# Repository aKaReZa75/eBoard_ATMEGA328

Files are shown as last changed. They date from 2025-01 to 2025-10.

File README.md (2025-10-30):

# ATMEGA328 Board
This repository involves designing, assembling, and testing an educational header board for the ATMEGA328 AVR microcontroller, compatible with the Arduino UNO.

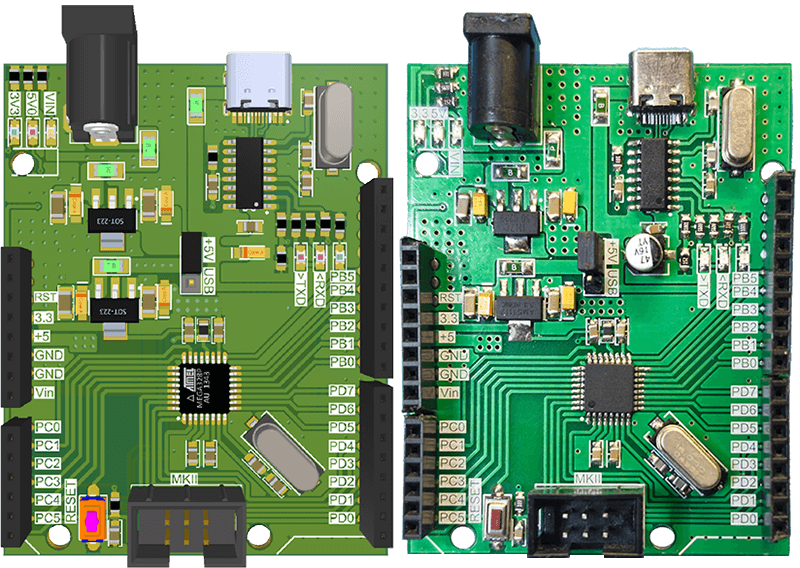
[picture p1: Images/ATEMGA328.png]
ATMEGA328 Shield


> [!IMPORTANT]
> Before sending the board files for PCB fabrication, **always make sure you are using the latest released version** of the project.
> Hardware issues or design flaws might exist in earlier versions and could be fixed in newer releases.
> To avoid costly mistakes and ensure the best performance, always refer to the **[Releases](../../releases)** section, where all known issues, updates, and version-specific notes are clearly documented.

## ATmega328 Pin Mapping Table
| **Arduino Pin** | **ATmega328 Pin** | **Functionality** |
| :---: | :---: | :--- |
| Analog Pin A0 | PC0 (PORTC, PIN0) | ADC0 |
| Analog Pin A1 | PC1 (PORTC, PIN1) | ADC1 |
| Analog Pin A2 | PC2 (PORTC, PIN2) | ADC2 |
| Analog Pin A3 | PC3 (PORTC, PIN3) | ADC3 |
| Analog Pin A4 | PC4 (PORTC, PIN4) | I2C (SDA) / ADC4 |
| Analog Pin A5 | PC5 (PORTC, PIN5) | I2C (SCL) / ADC5 |
| Digital Pin D0  | PD0 (PORTD, PIN0) | USART (RXD) |
| Digital Pin D1  | PD1 (PORTD, PIN1) | USART (TXD) |
| Digital Pin D2  | PD2 (PORTD, PIN2) | External Interrupt (INT0) |
| Digital Pin D3  | PD3 (PORTD, PIN3) | External Interrupt (INT1) / PWM (OC2B) |
| Digital Pin D4  | PD4 (PORTD, PIN4) | Timer/Counter (XCK/T0) |
| Digital Pin D5  | PD5 (PORTD, PIN5) | PWM (OC0B) / Timer1 |
| Digital Pin D6  | PD6 (PORTD, PIN6) | PWM (OC0A) / Analog Comparator |
| Digital Pin D7  | PD7 (PORTD, PIN7) | Analog Comparator Input |
| Digital Pin D8  | PB0 (PORTB, PIN0) | ICP1 / Clock Output (CLKO) |
| Digital Pin D9  | PB1 (PORTB, PIN1) | PWM (OC1A) |
| Digital Pin D10 | PB2 (PORTB, PIN2) | PWM (OC1B) / SPI (SS) |
| Digital Pin D11 | PB3 (PORTB, PIN3) | PWM (OC2A) / SPI (MOSI) |
| Digital Pin D12 | PB4 (PORTB, PIN4) | SPI (MISO) |
| Digital Pin D13 | PB5 (PORTB, PIN5) | SPI (SCK) / LED\_BUILTIN |

---

### **ADC (Analog-to-Digital Converter)**
| **Arduino Pin** | **ATmega328 Pin** | **ADC Channel** | **Other Functionality** |
| --- | --- | --- | --- |
| A0 | PC0 | ADC0 | — |
| A1 | PC1 | ADC1 | — |
| A2 | PC2 | ADC2 | — |
| A3 | PC3 | ADC3 | — |
| A4 | PC4 | ADC4 | I2C SDA |
| A5 | PC5 | ADC5 | I2C SCL |

### **Analog Comparator**
| **Arduino Pin** | **ATmega328 Pin** | **Functionality** |
| --- | --- | --- |
| D6 | PD6 | AIN0 |
| D7 | PD7 | AIN1 |

### **External Interrupts**
| **Arduino Pin** | **ATmega328 Pin** | **Interrupt** |
| --- | --- | --- |
| D2 | PD2 | INT0 |
| D3 | PD3 | INT1 |

### **Timers / PWM Outputs**
| **Arduino Pin** | **ATmega328 Pin** | **PWM / Timer** |
| --- | --- | ---|
| D6 | PD6 | OC0A (PWM) |
| D5 | PD5 | OC0B (PWM) |
| D9 | PB1 | OC1A (PWM) |
| D10 | PB2 | OC1B (PWM) |
| D11 | PB3 | OC2A (PWM) |
| D3 | PD3 | OC2B (PWM) |

| **Arduino Pin** | **ATmega328 Pin** | **Special Timer Function** |
| --- | --- | --- |
| D4 | PD4 | **T0** — Timer/Counter0 External Clock |
| D5 | PD5 | **T1** — Timer/Counter1 External Clock |
| D8 | PB0 | **ICP1** — Input Capture for Timer1 / CLKO |
| D6 | PD6 | AIN0 — Used in Analog Comparator (shared)  |
| D7 | PD7 | AIN1 — Used in Analog Comparator (shared)  |

### **USART (Serial Communication)**
| **Arduino Pin** | **ATmega328 Pin** | **USART Function** |
| --- | --- | --- |
| D0 | PD0 | RXD (Receive) |
| D1 | PD1 | TXD (Transmit) |

### **I2C Interface**
| **Arduino Pin** | **ATmega328 Pin** | **I2C Signal** |
| --- | --- | --- |
| A4 | PC4 | SDA |
| A5 | PC5 | SCL |

### **SPI Interface**
| **Arduino Pin** | **ATmega328 Pin** | **SPI Signal** |
| --- | --- | --- |
| D10 | PB2 | SS |
| D11 | PB3 | MOSI |
| D12 | PB4 | MISO |
| D13 | PB5 | SCK |

### **Other / General Purpose**
| **Arduino Pin** | **ATmega328 Pin** | **Functionality** |
| --- | --- | --- |
| D13 | PB5 | `LED_BUILTIN` / SPI Clock (SCK) |
| D12 | PB4 | **CKOUT** (System Clock Output) /SPI MISO  |

---

<table>
  <tr>
  <td valign="top">
  
  > [!TIP]  
  > If you're looking to better understand how to navigate and use my GitHub repositories — including exploring their structure, downloading or cloning projects, submitting issues, and asking questions,  
  > everything you need is clearly explained in this video:  
  > [aKaReZa 95 - Programming, Git - PART B](https://youtu.be/zYiUItVFRqQ)  
  > Make sure to check it out!
  
  </td>
    <td width="360" valign="middle" style="padding: 0;">
      <a href="https://youtu.be/zYiUItVFRqQ">
       aKaReZa 95 - Programming, Git - PART B Thumbnail
      </a>
    </td>
  </td>
  </tr>

<tr>
  <td valign="top">
  
  > [!IMPORTANT]
  > Begin your embedded systems journey with clarity and purpose. This episode outlines a structured roadmap for mastering microcontrollers, communication protocols, hardware design, and project development.  
  > Learn how to choose your specialization, follow curated playlists, and engage effectively with the community—ideal for learners seeking a scalable, goal-driven path into embedded engineering.  
  > [aKaReZa 124 – Embedded Systems Roadmap](https://youtu.be/3QYfv7A7aMc)  
  > Watch it now to kickstart your journey!
  
  </td>
  <td width="360" valign="middle" style="padding: 0;">
    <a href="https://youtu.be/3QYfv7A7aMc">
      aKaReZa 124 – Embedded Systems Roadmap Thumbnail
    </a>
  </td>
</tr>

  <tr>
  <td colspan="3">

  > [!CAUTION]
  > It is absolutely critical that you carefully read every single word of this document, line by line, to ensure you don't miss any details. Nothing can be overlooked.
      
  </td>
  </tr>  
</table>

## Detailed Description
| Aspect | Description |
|---|---|
| PCB Design Software  | Altium  V24.2.2 |
| PCB Layers | 2-Layer FR4 |
| Microcontroller | ATMEGA328 |
| Pin Type | Arduino UNO |
| Converter IC | CH340 |
| USB Port | TYPE-C |

## Resources

> [!TIP]
> The resources are detailed in the sections below.  
> To access any of them, simply click on the corresponding blue link.

- [Altium Library](https://github.com/aKaReZa75/Altium-Library)  
  ---  
   All PCB designs across all repositories and projects are built using this Altium Designer component library. It contains a wide range of verified footprints, schematic symbols, and 3D models, ensuring consistency and accuracy in PCB designs. If you're working on a new PCB, using this library will save you time and minimize errors.

- [PCB & Electronics Design Training](https://github.com/aKaReZa75/PCB)  
  ---  
  This repository is dedicated to **learning PCB design and electronics from scratch**. It covers everything from circuit theory to practical PCB layout techniques, including routing strategies, best practices, and component placement. Whether you're a beginner or an experienced designer, this resource will help you **improve your PCB design skills and create professional-quality boards**.

- [AVR Microcontroller Training](https://github.com/aKaReZa75/AVR)  
  ---  
  This repository provides a **comprehensive guide to AVR microcontroller programming**, covering everything from the fundamentals to advanced firmware development. Learn about **AVR architecture, peripheral interfacing, timers, interrupts, communication protocols**, and more through hands-on projects and real-world examples. Whether you're just starting or looking to refine your embedded programming skills, this resource will help you master AVR development.

- [Shopping Link](./ShoppingLink.md)  
  ---
  This document provides links to trusted suppliers where you can purchase all the essential components for this project, ensuring quality and reliability.

## Project Videos

```plaintext
Educational Boards
   ├── [aKaReZa 74 - eBoard, ATMEGA328 - PART A]
   │   ├─ Schematic — Voltage reg, UNO pinout, crystal, ADC filter.
   │   ├─ Communication — USBtoTTL + UART indicator.
   │   └─ Features — Auto Prog and library usage.
   │
   ├── [aKaReZa 76 - eBoard, ATMEGA328 - PART B]
   │   ├─ Fixes — Schematic issues and fuse improvements.
   │   ├─ Enhancements — USB Type-C, UART LEDs, voltage divider.
   │   └─ PCB Prep — Placement and routing readiness.
   │
   ├── [aKaReZa 88 - eBoard, ATMEGA328 - PART C]
   │   ├─ Routing — GPIO, USB, MCU, power tracks.
   │   ├─ Optimization — Polygon tool and hierarchical layout.
   │   └─ GitHub — Pull Request and version control.
   │
   └── [aKaReZa 102 - Repair, ATMEGA328 Soldering]
       ├─ Assembly — Voltage tests, MCU soldering, USB Type-C.
       ├─ Conversion — CH340 setup and verification.
       └─ Testing — Section-by-section validation.
```

<table style="border-collapse: collapse;">
  <tr>
    <td valign="top" style="padding: 0 10px;">
      <h3 style="margin: 0;">
        <a href="https://youtu.be/-ttv7IQRaWA">aKaReZa 74 – eBoard, ATMEGA328 - PART A</a>
      </h3>
      <p style="margin: 8px 0 0;">
        This video is the first in a new series called eBoard, which stands for Educational Boards. In this video, we design the schematic for an educational header board specifically for the ATMEGA328 microcontroller used in the channel's tutorials.
      </p>
    </td>
    <td width="360" valign="top" style="padding: 0;">
      <a href="https://youtu.be/-ttv7IQRaWA">
        aKaReZa 74 – eBoard, ATMEGA328 - PART A Thumbnail
      </a>
    </td>
  </tr>

  <tr>
    <td valign="top" style="padding: 0 10px;">
      <h3 style="margin: 0;">
        <a href="https://youtu.be/Ipy6SqzdZnI">aKaReZa 76 – eBoard, ATMEGA328 - PART B</a>
      </h3>
      <p style="margin: 8px 0 0;">
        In this video, we fix a few issues in the schematic, upgrade and change several sections, and then transfer all components to the PCB. We arrange the components and prepare them for routing.
      </p>
    </td>
    <td width="360" valign="top" style="padding: 0;">
      <a href="https://youtu.be/Ipy6SqzdZnI">
        aKaReZa 76 – eBoard, ATMEGA328 - PART B Thumbnail
      </a>
    </td>
  </tr>

  <tr>
    <td valign="top" style="padding: 0 10px;">
      <h3 style="margin: 0;">
        <a href="https://youtu.be/WwyNDgpCwrc">aKaReZa 88 – eBoard, ATMEGA328 - PART C</a>
      </h3>
      <p style="margin: 8px 0 0;">
        In this video, we complete the routing for the ATMEGA328 educational board and get familiar with related tips.
      </p>
    </td>
    <td width="360" valign="top" style="padding: 0;">
      <a href="https://youtu.be/WwyNDgpCwrc">
        aKaReZa 88 – eBoard, ATMEGA328 - PART C Thumbnail
      </a>
    </td>
  </tr>

  <tr>
    <td valign="top" style="padding: 0 10px;">
      <h3 style="margin: 0;">
        <a href="https://youtu.be/j-jOPXrMTt0">aKaReZa 102 – Repair, ATMEGA328 Soldering</a>
      </h3>
      <p style="margin: 8px 0 0;">
        Step-by-step soldering of an ATMEGA328-based board, covering power input, voltage regulators (12V, 5V, 3.3V), microcontroller placement, USB Type-C port installation, CH340 for USB-to-UART conversion, final connections, bootloader programming, and full board testing to ensure proper functionality.
      </p>
    </td>
    <td width="360" valign="top">
      <a href="https://youtu.be/j-jOPXrMTt0">
        aKaReZa 102 – Repair, ATMEGA328 Soldering Thumbnail
      </a>
    </td>
  </tr>

</table>

# 💻 How to Use Git and GitHub
To access the repository files and save them on your computer, there are two methods available:
1. **Using Git Bash and Cloning the Repository**
   - This method is more suitable for advanced users and those familiar with command-line tools.
   - By using this method, you can easily receive updates for the repository.

2. **Downloading the Repository as a ZIP file**
   - This method is simpler and suitable for users who are not comfortable with command-line tools.
   - Note that with this method, you will not automatically receive updates for the repository and will need to manually download any new updates.
     
## Clone using the URL.
First, open **Git Bash** :
-  Open the folder in **File Explorer** where you want the library to be stored.
-  **Right-click** inside the folder and select the option **"Open Git Bash here"** to open **Git Bash** in that directory.

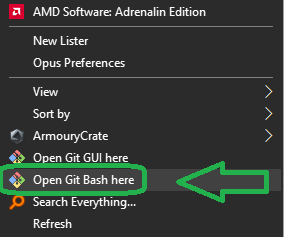
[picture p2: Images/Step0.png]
open Git Bash


> [!NOTE] 
> If you do not see the "Open Git Bash here" option, it means that Git is not installed on your system.  
> You can download and install Git from [this link](https://git-scm.com/downloads).  
> For a tutorial on how to install and use Git, check out [this video](https://youtu.be/BsykgHpmUt8).
  
-  Once **Git Bash** is open, run the following command to clone the repository:

 ```bash
git clone https://github.com/aKaReZa75/eBoard_ATMEGA328.git
```
- You can copy the above command by either:
- Clicking on the **Copy** button on the right of the command.
- Or select the command text manually and press **Ctrl + C** to copy.
- To paste the command into your **Git Bash** terminal, use **Shift + Insert**.

Clone the Repository

- Then, press Enter to start the cloning operation and wait for the success message to appear.

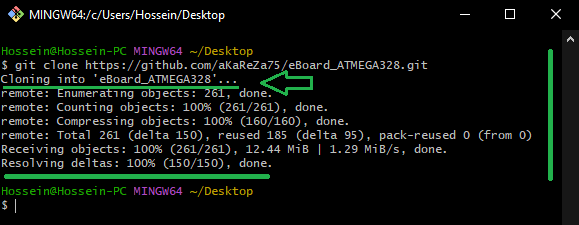
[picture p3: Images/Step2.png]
Open the Library File


> [!IMPORTANT]
> Please keep in mind that the numbers displayed in the image might vary when you perform the same actions.  
> This is because repositories are continuously being updated and expanded. Nevertheless, the overall process remains unchanged.

> [!NOTE]
> Advantage of Cloning the Repository:  
> - **Receiving Updates:** By cloning the repository, you can easily and automatically receive new updates.  
> - **Version Control:** Using Git allows you to track changes and revert to previous versions.  
> - **Team Collaboration:** If you are working on a project with a team, you can easily sync changes from team members and collaborate more efficiently.  

## Download Zip
If you prefer not to use Git Bash or the command line, you can download the repository directly from GitHub as a ZIP file.  
Follow these steps:  
1. Navigate to the GitHub repository page and Locate the Code button:
- On the main page of the repository, you will see a green Code button near the top right corner.

2. Download the repository:
- Click the Code button to open a dropdown menu.
- Select Download ZIP from the menu.

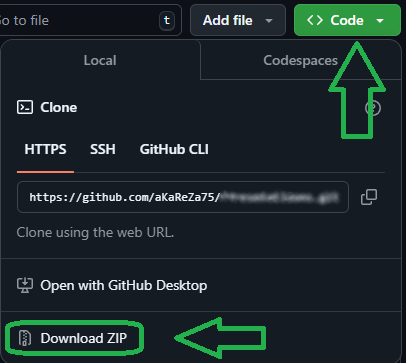
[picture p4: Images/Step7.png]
Download Zip
    

3. Save the ZIP file:
- Choose a location on your computer to save the ZIP file and click Save.

4. Extract the ZIP file:
- Navigate to the folder where you saved the ZIP file.
- Right-click on the ZIP file and select Extract All... (Windows) or use your preferred extraction tool.
- Choose a destination folder and extract the contents.

5. Access the repository:
- Once extracted, you can access the repository files in the destination folder.

> [!IMPORTANT]
> - No Updates: Keep in mind that downloading the repository as a ZIP file does not allow you to receive updates.    
>   If the repository is updated, you will need to download it again manually.  
> - Ease of Use: This method is simpler and suitable for users who are not comfortable with Git or command-line tools.

# 📝 How to Ask Questions
If you have any questions or issues, you can raise them through the **"Issues"** section of this repository. Here's how you can do it:  

1. Navigate to the **"Issues"** tab at the top of the repository page.  

  Issues

2. Click on the **"New Issue"** button.  
   
  New Issue

3. In the **Title** field, write a short summary of your issue or question.  

4. In the "Description" field, detail your question or issue as thoroughly as possible. You can use text formatting, attach files, and assign the issue to someone if needed. You can also use text formatting (like bullet points or code snippets) for better readability.  

5. Optionally, you can add **labels**, **type**, **projects**, or **milestones** to your issue for better categorization.  

6. Click on the **"Submit new issue"** button to post your question or issue.
   
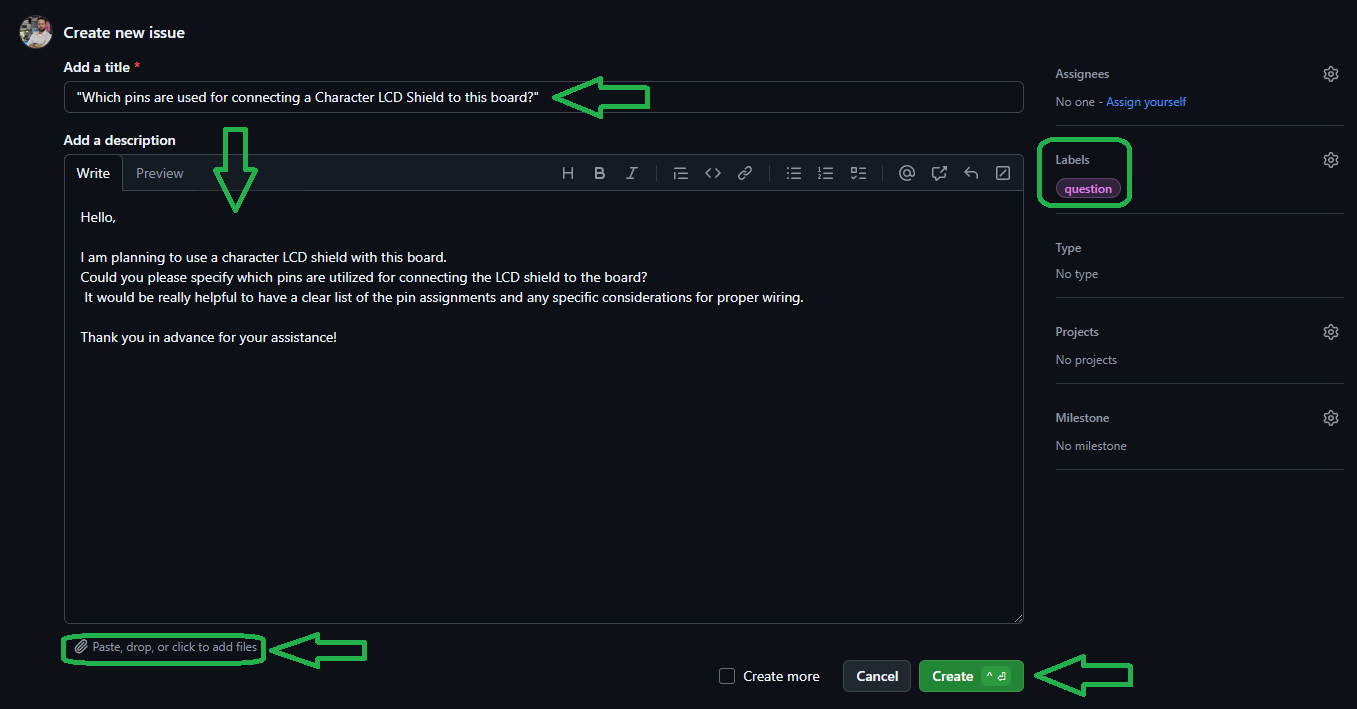
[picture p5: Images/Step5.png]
Submeet New Issue
  

I will review and respond to your issue as soon as possible. Your participation helps improve the repository for everyone!  

> [!TIP]
> - Before creating a new issue, please check the **"Closed"** section to see if your question has already been answered.  
>   Closed section  
> - Write your question clearly and respectfully to ensure a faster and better response.  
> - While the examples provided above are in English, feel free to ask your questions in **Persian (فارسی)** as well.  
> - There is no difference in how they will be handled!  

> [!NOTE]
> Pages and interfaces may change over time, but the steps to create an issue generally remain the same.

# 🤝 Contributing to the Repository
To contribute to this repository, please follow these steps:
1. **Fork the Repository**  
2. **Clone the Forked Repository**  
3. **Create a New Branch**  
4. **Make Your Changes**  
5. **Commit Your Changes**  
6. **Push Your Changes to Your Forked Repository**  
7. **Submit a Pull Request (PR)**  

> [!NOTE]
> Please ensure your pull request includes a clear description of the changes you’ve made.
> Once submitted, I will review your contribution and provide feedback if necessary.

# 🌟 Support Me
If you found this repository useful:
- Subscribe to my [YouTube Channel](https://www.youtube.com/@aKaReZa75).
- Share this repository with others.
- Give this repository and my other repositories a star.
- Follow my [GitHub account](https://github.com/aKaReZa75).

# 📜 License
This project is licensed under the GPL-3.0 License. This license grants you the freedom to use, modify, and distribute the project as long as you:
- Credit the original authors: Give proper attribution to the original creators.
- Disclose source code: If you distribute a modified version, you must make the source code available under the same GPL license.
- Maintain the same license: When you distribute derivative works, they must be licensed under the GPL-3.0 too.
- Feel free to use it in your projects, but make sure to comply with the terms of this license.
  
# ✉️ Contact Me
Feel free to reach out to me through any of the following platforms:
- 📧 [Email: aKaReZa75@gmail.com](mailto:aKaReZa75@gmail.com)
- 🎥 [YouTube: @aKaReZa75](https://www.youtube.com/@aKaReZa75)
- 💼 [LinkedIn: @akareza75](https://www.linkedin.com/in/akareza75)

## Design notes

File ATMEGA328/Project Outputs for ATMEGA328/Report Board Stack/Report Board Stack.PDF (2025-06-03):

# Board Stack Report

Stack Up | Layer Stack
Layer | Board Layer Stack | Name | Material | Thickness Constant Dk | | | Coverlay expansion | Orientation | Copper Orientation
1 | | Top Overlay | | 0mm
2 | | Top Solder | Solder Resist | 0.01016mm | 3.5 | 3.5 0mm
3 | | Top Layer | | 0.03556mm | | | | BodyUp | Above
4 | | Dielectric 1 | FR-4 | 1.5mm | 4.8 | 4.8
5 | | Bottom Layer | | 0.03556mm | | | | BodyDown | Below
6 | | Bottom Solder | Solder Resist | 0.01016mm | 3.5 | 3.5 0mm
7 | | Bottom Overlay | | 0mm
| Height : 1.59144mm

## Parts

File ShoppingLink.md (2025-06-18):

# 📦 Components Purchase Links
This section provides a comprehensive list of components required for the "ATMEGA328 Board
" project.
Each item includes direct purchase links from reliable Iranian electronics suppliers, with recommended quantities for both essential needs and future prototyping.

## Capacitor
- [ ] [**Cap_0805_22p**](https://lionelectronic.ir/products/1950-TCC0805COG220J500BT) Quantity: 4, Prefer: 25, Supplier: LionElectronic
- [ ] [**Cap_0805_10n**](https://lionelectronic.ir/products/1973-0805B103K500NT) Quantity: 1, Prefer: 25, Supplier: LionElectronic
- [ ] [**Cap_0805_100n**](https://lionelectronic.ir/products/2791-CL21B104KBCNNNC) Quantity: 7, Prefer: 25, Supplier: LionElectronic
- [ ] [**Cap_1206_100n**](https://lionelectronic.ir/products/5156-C3216NP01H104J160AA) Quantity: 4, Prefer: 25, Supplier: LionElectronic
- [ ] [**Cap_Tantal_10u_16V_A**](https://lionelectronic.ir/products/2047-TAJA106K016RNJ) Quantity: 2, Prefer: 5, Supplier: LionElectronic 
- [ ] [**Cap_Tantal_22u_6.3V_A**](https://lionelectronic.ir/products/2051-TAJA226M006RNJ) Quantity: 2, Prefer: 5, Supplier: LionElectronic 
- [ ] [**Cap_Tantal_10u_10V_A**](https://lionelectronic.ir/products/2046-TAJA106K010RNJ) Quantity: 3, Prefer: 10, Supplier: LionElectronic **(Instead of: Cap_Tantal_10u_6.3V_A)**

## Connector
- [ ] [**Power_Jack**](https://lionelectronic.ir/products/4704-DC005) Quantity: 2, Prefer: 25, Supplier: LionElectronic  
- [ ] [**Con_BoxHeadr_2x3**](https://roboeq.ir/products/detail/1504056/%D8%A8%D8%A7%DA%A9%D8%B3-%D9%87%D8%AF%D8%B1-3-2-BOX-HEADER-%D8%B5%D8%A7%D9%81/) Quantity: 1, Prefer: 5, Supplier: RoboEQ  
- [ ] [**Con_IDC_2x3**](https://roboeq.ir/products/detail/1504059/%D8%A2%DB%8C-%D8%AF%DB%8C-%D8%B3%DB%8C-IDC-2-3/) Quantity: 1, Prefer: 5, Supplier: RoboEQ  
- [ ] [**Flat Cable**](https://roboeq.ir/products/detail/1301002/%DA%A9%D8%A7%D8%A8%D9%84-20-%D8%B1%D8%B4%D8%AA%D9%87-%D9%81%D9%84%D8%AA/) Quantity: 0.2, Prefer: 1, Supplier: RoboEQ  
- [ ] [**Male_PinHeader**](https://lionelectronic.ir/products/5356-PLS-2.54-1X40GF) Quantity: 0.1, Prefer: 1, Supplier: LionElectronic  
- [ ] [**Female_PinHeader**](https://lionelectronic.ir/products/5360-PBS-2.54-1X40GF) Quantity: 1, Prefer: 2, Supplier: LionElectronic  
- [ ] [**USB_Type_C_12**](https://ickala.com/usb-onboard/29448-usb-smd-onboard.html) Quantity: 1, Prefer: 2, Supplier: ICkala

## Integrated Circuit
- [ ] [**IC_ATMEGA328P**](https://lionelectronic.ir/products/293-ATMEGA328P-AU) Quantity: 1, Prefer: 1, Supplier: LionElectronic  
- [ ] [**Reg_AMS1117-5**](https://lionelectronic.ir/products/2189-AMS1117-5.0) Quantity: 1, Prefer: 3, Supplier: LionElectronic  
- [ ] [**Reg_AMS1117-3.3**](https://lionelectronic.ir/products/868-AMS1117-3.3) Quantity: 1, Prefer: 3, Supplier: LionElectronic  
- [ ] [**IC_CH340G**](https://lionelectronic.ir/products/3547-CH340G) Quantity: 1, Prefer: 2, Supplier: LionElectronic  

## Inductor
- [ ] [**Ind_0805_100u**](https://lionelectronic.ir/products/2146-EBLS201212-101K) Quantity: 1, Prefer: 5, Supplier: LionElectronic

## Other
- [ ] [**Fuse_1206_0.5A**](https://lionelectronic.ir/products/1891-JFC1206-0500FS-63V-0.5A) Quantity: 3, Prefer: 10, Supplier: LionElectronic  
- [ ] [**Fuse_1206_3A**](https://lionelectronic.ir/products/1894-JFC1206-1300FS-63V-3A) Quantity: 1, Prefer: 5, Supplier: LionElectronic
- [ ] [**Crystal 12MHz**](https://lionelectronic.ir/products/2096-XTAL-12MHZ%28HC-49SMD%29) Quantity: 1, Prefer: 5, Supplier: LionElectronic
- [ ] [**Crystal_16MHz**](https://lionelectronic.ir/products/2101-XTAL-16MHZ%28HC-49SMD%29) Quantity: 1, Prefer: 5, Supplier: LionElectronic
- [ ] [**Jumper**](https://ickala.com/pin-header-jumper/26295-jumper2pin-%D9%82%D8%B1%D9%85%D8%B2.html) Quantity: 1, Prefer: 10, Supplier: ICKala

## Resistor
- [ ] [**Res_0805_220b**](https://lionelectronic.ir/products/1565-SER0805J220R) Quantity: 1, Prefer: 25, Supplier: LionElectronic  
- [ ] [**Res_0805_680b**](https://lionelectronic.ir/products/1571-0805W8J0681T5E) Quantity: 3, Prefer: 25, Supplier: LionElectronic
- [ ] [**Res_0805_1K**](https://lionelectronic.ir/products/1573-RS-05K102JT) Quantity: 3, Prefer: 25, Supplier: LionElectronic  
- [ ] [**Res_0805_1.8K**](https://lionelectronic.ir/products/1576-0805W8J0182T5E) Quantity: 2, Prefer: 25, Supplier: LionElectronic
- [ ] [**Res_0805_4.7K**](https://lionelectronic.ir/products/1581-SER0805J4K7) Quantity: 2, Prefer: 25, Supplier: LionElectronic 
- [ ] [**Res_0805_10K**](https://lionelectronic.ir/products/1585-SCR0805J10K) Quantity: 2, Prefer: 25, Supplier: LionElectronic

## Semiconductore
- [ ] [**LED_0805_Red**](https://lionelectronic.ir/products/2207-XL-2012SURC) Quantity: 3, Prefer: 10, Supplier: LionElectronic  
- [ ] [**LED_0805_Yellow**](https://lionelectronic.ir/products/3267-XL-2012UYC) Quantity: 1, Prefer: 10, Supplier: LionElectronic  
- [ ] [**LED_0805_Green**](https://lionelectronic.ir/products/3265-XL-2012SYGC) Quantity: 2, Prefer: 10, Supplier: LionElectronic

## Switch
- [ ] [**SW_PushButton-6-3.7-2.5**](https://lionelectronic.ir/products/4165-TS365TP) Quantity: 1, Prefer: 5, Supplier: LionElectronic

# 🌟 Support Me
If you found this repository useful:
- Subscribe to my [YouTube Channel](https://www.youtube.com/@aKaReZa75).
- Share this repository with others.
- Give this repository and my other repositories a star.
- Follow my [GitHub account](https://github.com/aKaReZa75).

# ✉️ Contact Me
Feel free to reach out to me through any of the following platforms:
- 📧 [Email: aKaReZa75@gmail.com](mailto:aKaReZa75@gmail.com)
- 🎥 [YouTube: @aKaReZa75](https://www.youtube.com/@aKaReZa75)
- 💼 [LinkedIn: @akareza75](https://www.linkedin.com/in/akareza75)

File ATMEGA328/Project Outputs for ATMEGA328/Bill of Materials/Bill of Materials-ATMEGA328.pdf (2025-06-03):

Altium Limited Confidential | 6/3/2025 | Page 1

# Bill of Materials

Title: Bill of Materials for Project [ATMEGA328.PrjPcb] (No PCB Document Selected) Project: ATMEGA328 EB
Company github.com/aKaReZa75
Variant: None
Revision: 1.1
Inflow | LibRef | Footprint | Value | Rating | Package | Type | Description | Comment | Quantity
inflow? | Cap_Multi_SMD_100nF_0805 | CAP 0805/2012 | 100n | 50V | 0805 | MultiLayer | Bipolar ceramic capacitor SMD | 100n | 7
inflow? | Cap_Multi_SMD_100nF_1206 | CAP 1206/3216 | 100n | 50V | 1206 | MultiLayer | Bipolar ceramic capacitor SMD | 100n | 4
inflow? | Cap_Multi_SMD_0805 | CAP 0805/2012 | 10n | Rating? | 0805 | MultiLayer | Bipolar ceramic capacitor SMD | 10n | 1
inflow? | Cap_Multi_SMD_0805 | CAP 0805/2012 | 22p | Rating? | 0805 | MultiLayer | Bipolar ceramic capacitor SMD | 22p | 4
inflow? | Cap_Tantalum | SMT_C_Tantalum_A | 10u | 16V, 6.3V | Package? | Tantalum | Tantalum Capacitor,TAJ Series-SMD | 10u | 3
inflow? | Cap_Tantalum | SMT_C_Tantalum_A | 22u | 6.3V | Package? | Tantalum | Tantalum Capacitor,TAJ Series-SMD | 22u | 2
inflow? | Con_Arduino_UNO_Con | ARDUINO_UNO_CONNECTOR UNO | | Rating? | Package? | Type? | Arduino UNO Connector | UNO | 1
6127 | Con_Power_Jack | Power Jack BIG | Female | Rating? | Package? | Type? | Power Jack | Female | 1
inflow? | Con_Prog_MKII_ISP | IDC_2X3 | 3x2 | Rating? | Package? | Type? | 6 Pin Standard ISP Header For MKII | 3x2 | 1
inflow? | Con_USB_C | HRO_TYPE-C-31-M-12 - | 12b | Rating? | SMD | C | USB C Female Connector | 12b | 1
inflow? | IC_Converter_CH340G | SO16_M | CH340G | Rating? | SO-16 | USB to TTL | TTL To USB Chip | CH340G | 1
inflow? | IC_MCU_ATmega328P_SMD | ATMEGA328 | ATmega328P Rating? | | Package? | Type? | 8-Bit AVR Microcontroller with 32K | ATmega328P | 1
5217 | IC_Reg_AMS1117_3.3 | SOT223_M | 3.3V | 1A | SOT223 | LDO | 1'A Positive voltage regulator | 3.3V | 1
5217 | IC_Reg_AMS1117_3.3 | SOT223_M | 5V | 1A | SOT223 | LDO | 1'A Positive voltage regulator | 5V | 1
inflow? | Ind_SMD_0805 | IND0805 | 100u | Rating? | 0805 | SMD | Inductor | 100u | 1
inflow? | Other_Elec_Fuse_SMD | 1206_F | 0.5A | Rating? | 1206 | Fast | Short circiut protection | 0.5A | 2
inflow? | Other_Elec_Fuse_SMD | 1206_F | 3A | Rating? | 1206 | Fast | Short circiut protection | 3A | 1
inflow? | Other_Elec_Fuse_SMD | 1206_F | 500m | Rating? | 1206 | Fast | Short circiut protection | 500m | 1
inflow? | Other_Elec_Xtal_SMD | Crystal SMD | 12M | Rating? | SMD | Quartz | Crystal Oscillator | 12M | 2
inflow? | Res_SMD_0805 | RES 0805 (2012X06L) | 1K | 0.125W | 0805 | 10% | Resistor | 1K | 3
inflow? | Res_SMD_0805 | RES 0805 (2012X06L) | 1.8K | 0.125W | 0805 | 10% | Resistor | 1.8K | 2
inflow? | Res_SMD_0805 | RES 0805 (2012X06L) | 4.7K | 0.125W | 0805 | 10% | Resistor | 4.7K | 2
inflow? | Res_SMD_0805 | RES 0805 (2012X06L) | 10K | 0.125W | 0805 | 10% | Resistor | 10K | 2
inflow? | Res_SMD_0805 | RES 0805 (2012X06L) | 220b | 0.125W | 0805 | 10% | Resistor | 220b | 1
inflow? | Res_SMD_0805 | RES 0805 (2012X06L) | 680 | 0.125W | 0805 | 10% | Resistor | 680 | 2
inflow? | Res_SMD_0805 | RES 0805 (2012X06L) | 680b | 0.125W | 0805 | 10% | Resistor | 680b | 1
inflow? | Semi_LED_SMD | LED 0805/2012 GREEN | Green | Rating? | Package? | LED | LED | Green | 2
inflow? | Semi_LED_SMD | LED 0805/2012 RED | Red | Rating? | Package? | LED | LED | Red | 3
inflow? | Semi_LED_SMD | LED 0805/2012 YELLOW | Yellow | Rating? | Package? | LED | LED | Yellow | 1
5145 | SW_Other_JSelector_Dip | jumper selector | 0b | Rating? | Dip | Selector | Jumper Selector | 0b | 1
8260 | SW_PushButton_2_SMD | SW_PB_SMD_2PIN_SPST_6X | PB | 2b | SMD | Vertical | SMT Tactile ‎Switch | PB | 1
Approved Notes | | | | | | | | | 57

6/3/2025 3:09 PM
Hossein Bagheri

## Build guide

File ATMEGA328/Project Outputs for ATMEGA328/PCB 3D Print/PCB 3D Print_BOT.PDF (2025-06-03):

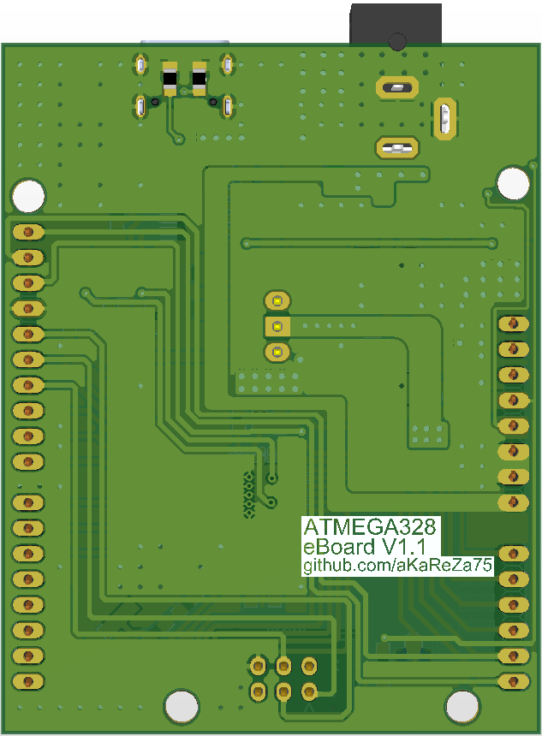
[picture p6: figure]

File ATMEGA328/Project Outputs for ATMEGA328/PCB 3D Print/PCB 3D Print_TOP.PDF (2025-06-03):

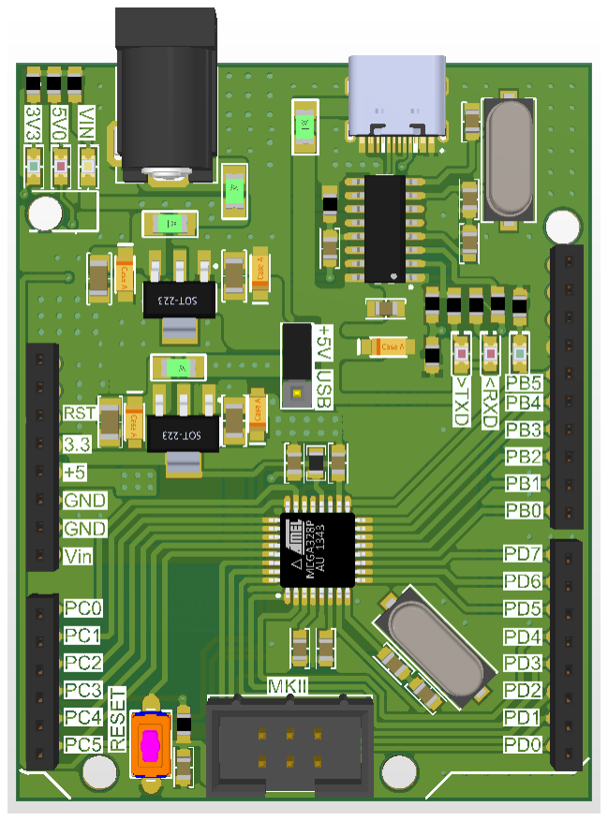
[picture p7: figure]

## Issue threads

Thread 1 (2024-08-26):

موارد اصلاحی در شماتیک ATMEGA328

aKaReZa75, 2024-08-26:
1. تغییر کانکتور USB به TYPE C
2. تغییر فیوز ورودی به 1206
3. اصلاح اتصال LED های UART
4. اضافه کردن LED به پایه 13
5. اضافه کردن رگولاتور 5 ولت
6. تقسیم مقاومتی برای پایه TX مبدل USB

Closed 2024-08-26.

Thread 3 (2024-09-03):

تغذیه ch340g

mehi79, 2024-09-03:
سلام مهندس خسته نباشید . ی سوالی داشتم راجب تغذیه ایسی usb به سریال . اگر ولتاژ تغذیه این ایسی رو 3.3 ولت بدیم مشکلی پیشش میاد ؟ چون دیتایی که داره میگیره از پورت کامپیوتر هست .
یک در خواست هم داشتم . اگر امکانش هست داخل ویدیو نحوه ایجاد pull request رو بگید .چون من از پروژه ها ( هم eboard و هم RCS ) fork میگیرم و تغییرات هم اعمال میکنم اما نمیتونم pull request بفرستم یعنی اصلا تغییرات من رو شناسایی نمیکنه و میگه تغییری برای مقایسه وجود نداره

aKaReZa75, 2024-09-04:
سلام دوست عزیز، خیر مشکلی پیش نمیاد و میتونه کار کنه.
شما باید تغییراتی رو که توی سیستم خدتون اعمال کردین ( منظورم کامیت های هست) بعد ازون از دستور git push استفاده کنید که بیاد روی گیتهابتون، و بعد ازین دیگه اون میتونید پول ریکوئست بفرستین.

Closed 2024-12-30.

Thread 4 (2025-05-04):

اصلاح قطعات و BOM

aKaReZa75, 2025-05-04:
1.خازن C10 به اشتباه از نوع آلمینیوم انتخاب شده و باید تانتال میببود
2.رگولاتور U4 به اشتباه مدل 3.3 انتخاب شده که باید 5 میبود
3.ظاهرا کانکتور Type C مدل 16 پین بهتر توی بازار پیدا میشه، پس پیشنهاد میشه که این کانکتور به مدل 16 پین تغییر پیدا کنه
4.خازن C9 به اشتباه برای اون پیکو نوشته شد ولی باید 10 نانو باشد

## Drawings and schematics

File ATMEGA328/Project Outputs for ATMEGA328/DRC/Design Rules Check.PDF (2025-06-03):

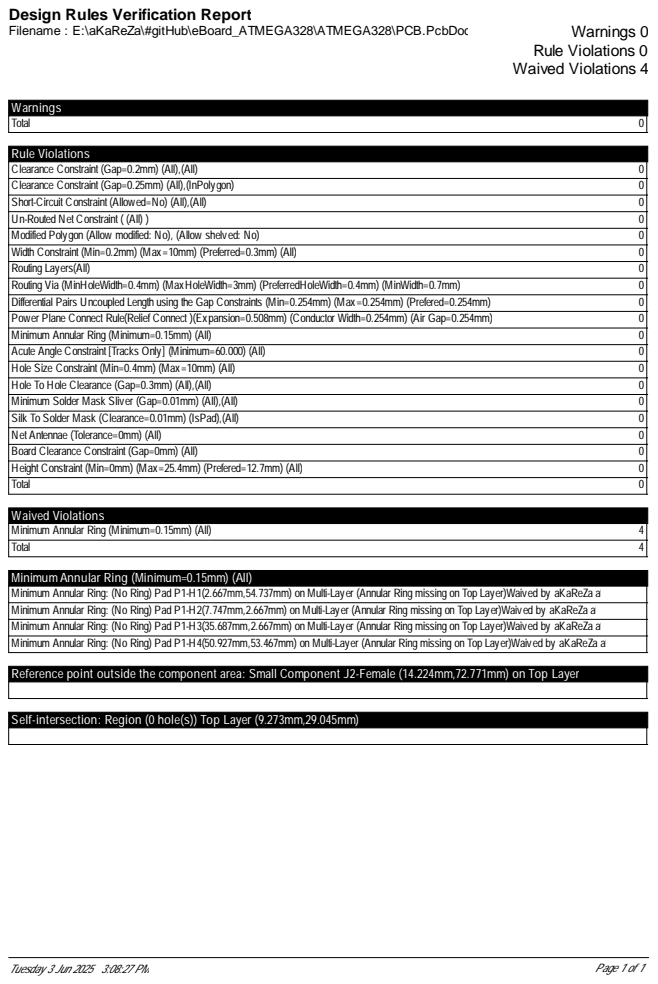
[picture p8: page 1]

Design Rules Verification Report

Minimum Annular Ring (Minimum=0.15mm) (All)
Minimum Annular Ring: (No Ring) Pad P1-H1(2.667mm,54.737mm) on Multi-Layer (Annular Ring missing on Top Layer)Waived by aKaReZa at
Minimum Annular Ring: (No Ring) Pad P1-H2(7.747mm,2.667mm) on Multi-Layer (Annular Ring missing on Top Layer)Waived by aKaReZa at
Minimum Annular Ring: (No Ring) Pad P1-H3(35.687mm,2.667mm) on Multi-Layer (Annular Ring missing on Top Layer)Waived by aKaReZa at
Minimum Annular Ring: (No Ring) Pad P1-H4(50.927mm,53.467mm) on Multi-Layer (Annular Ring missing on Top Layer)Waived by aKaReZa at

Reference point outside the component area: Small Component J2-Female (14.224mm,72.771mm) on Top Layer

Self-intersection: Region (0 hole(s)) Top Layer (9.273mm,29.045mm)

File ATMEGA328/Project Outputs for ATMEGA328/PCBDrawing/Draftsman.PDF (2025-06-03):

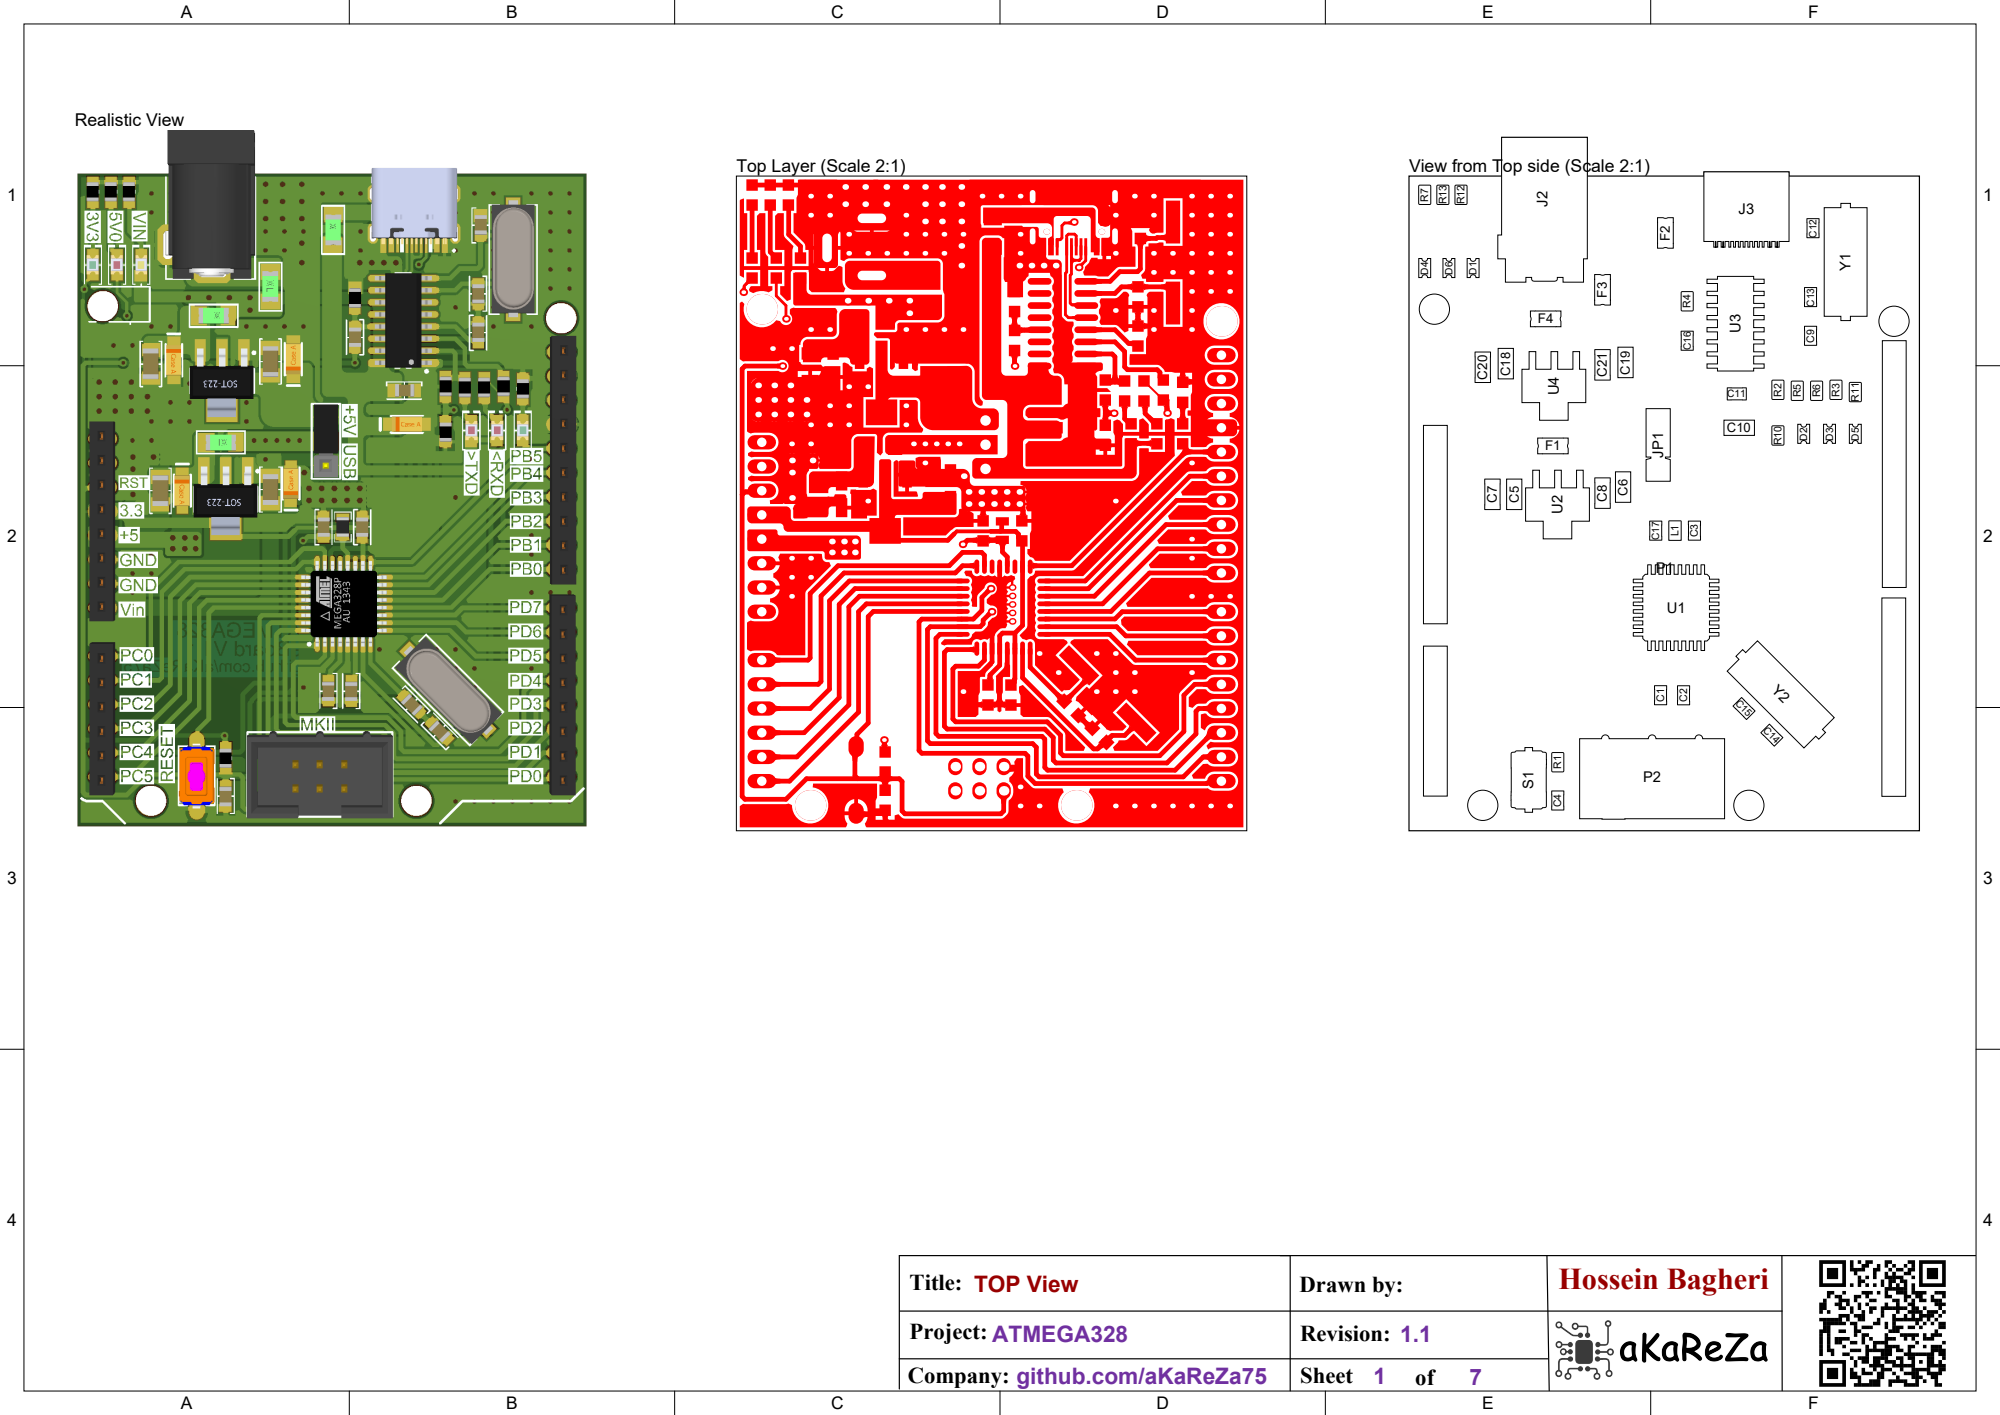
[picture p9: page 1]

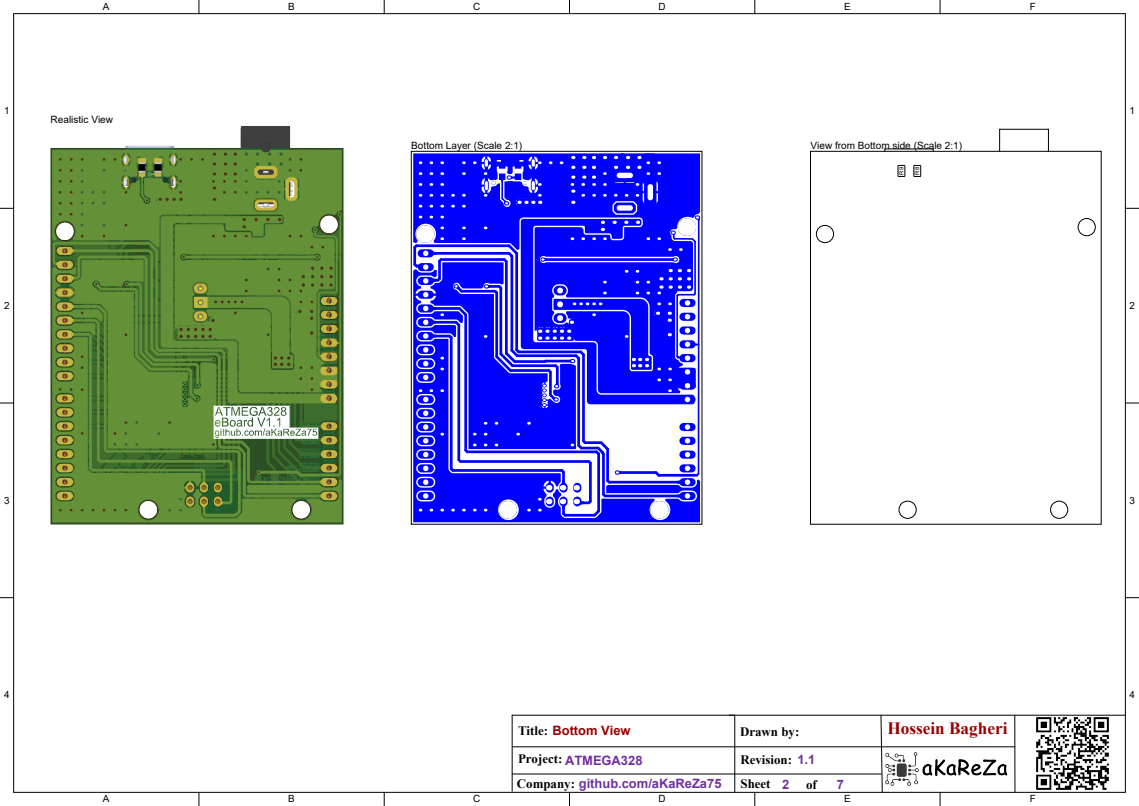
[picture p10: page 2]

View from Bottom side (Scale 2:1)

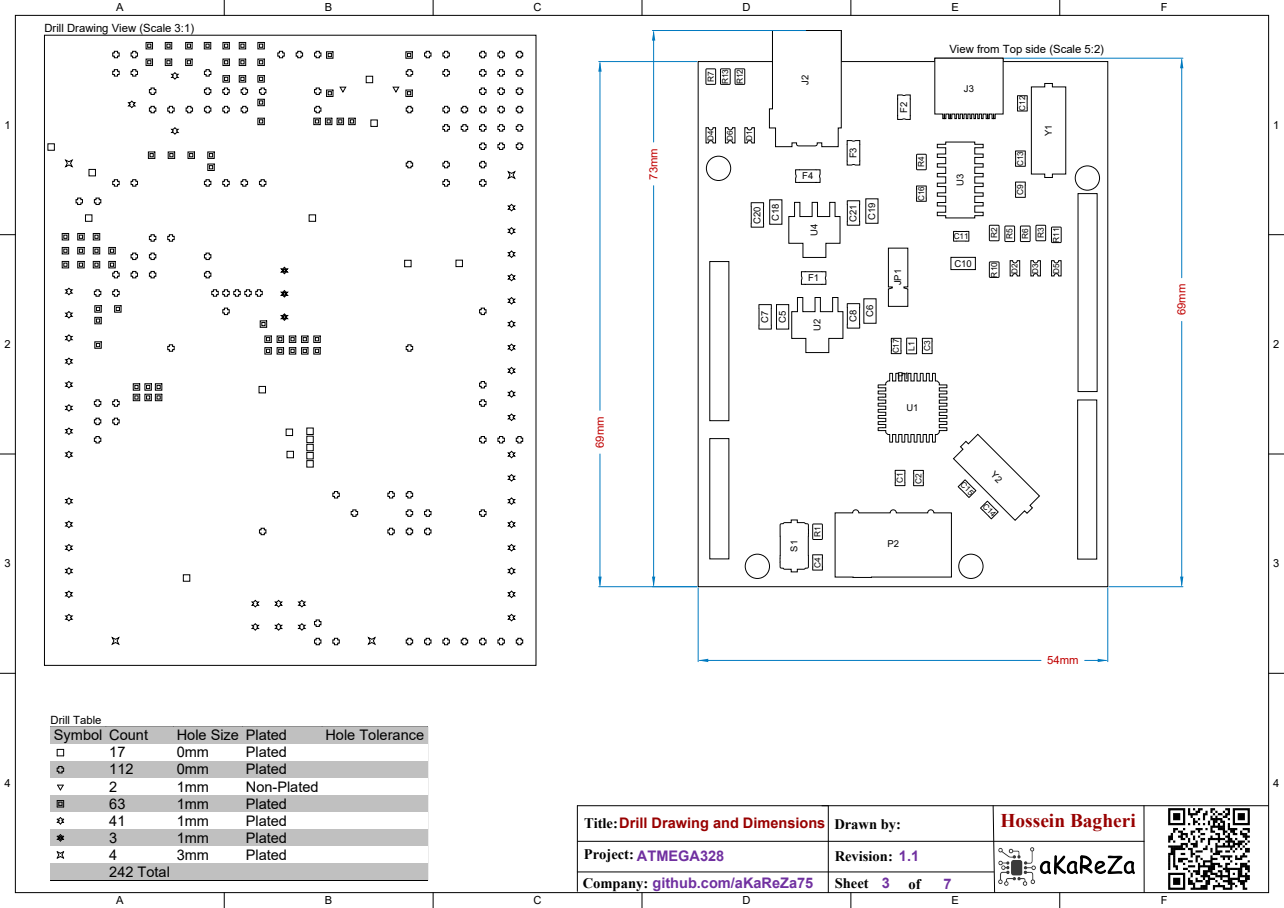
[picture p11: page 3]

Drill Drawing View (Scale 3:1)

View from Top side (Scale 5:2)

Symbol | Count | Hole Size | Plated | Hole Tolerance

17 | 0mm | Plated
112 | 0mm | Plated
2 | 1mm | Non-Plated
63 | 1mm | Plated
41 | 1mm | Plated
3 | 1mm | Plated
4 | 3mm | Plated
242 Total

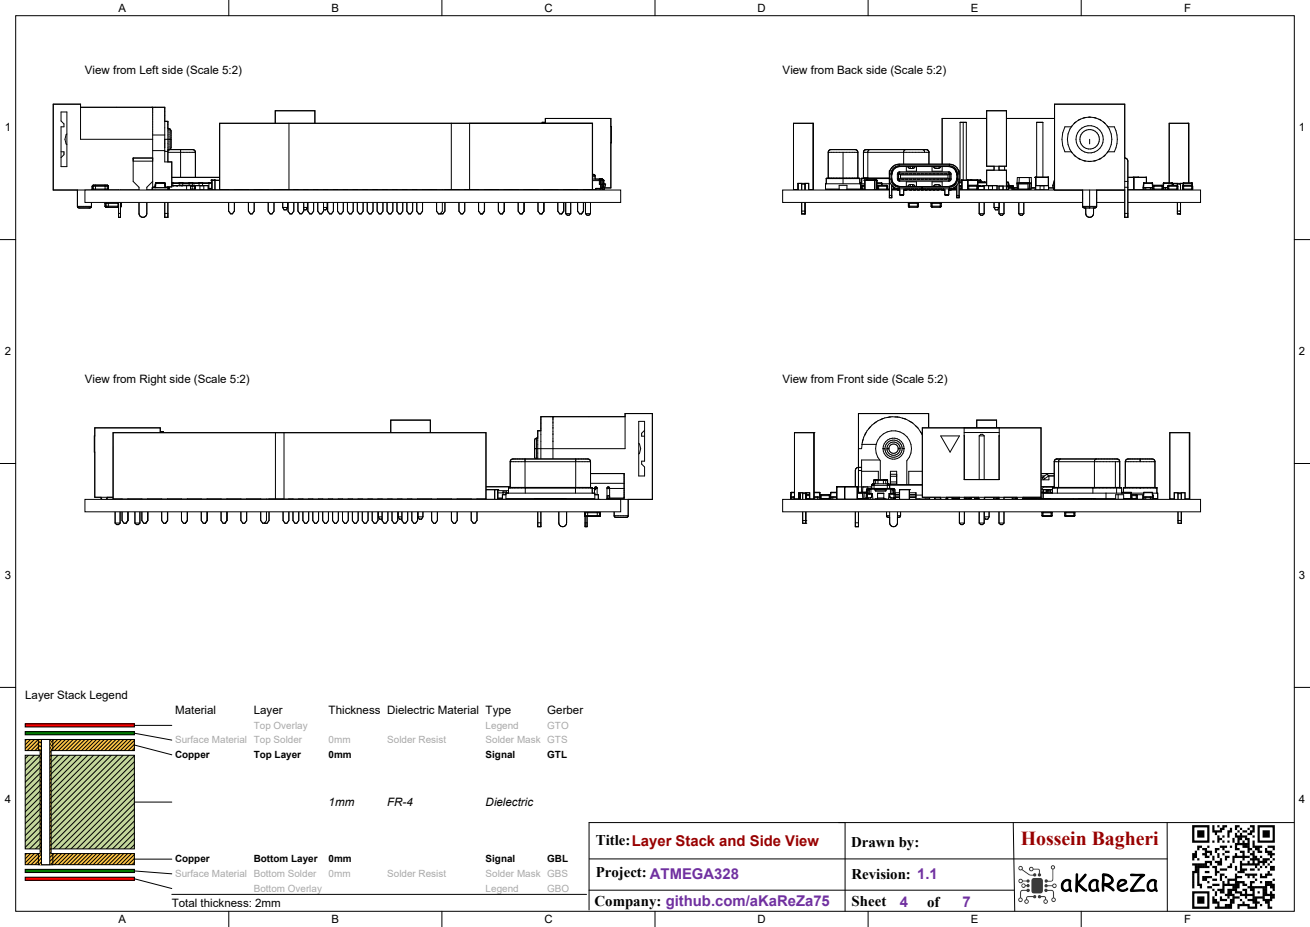
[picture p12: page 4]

View from Left side (Scale 5:2)

View from Back side (Scale 5:2)

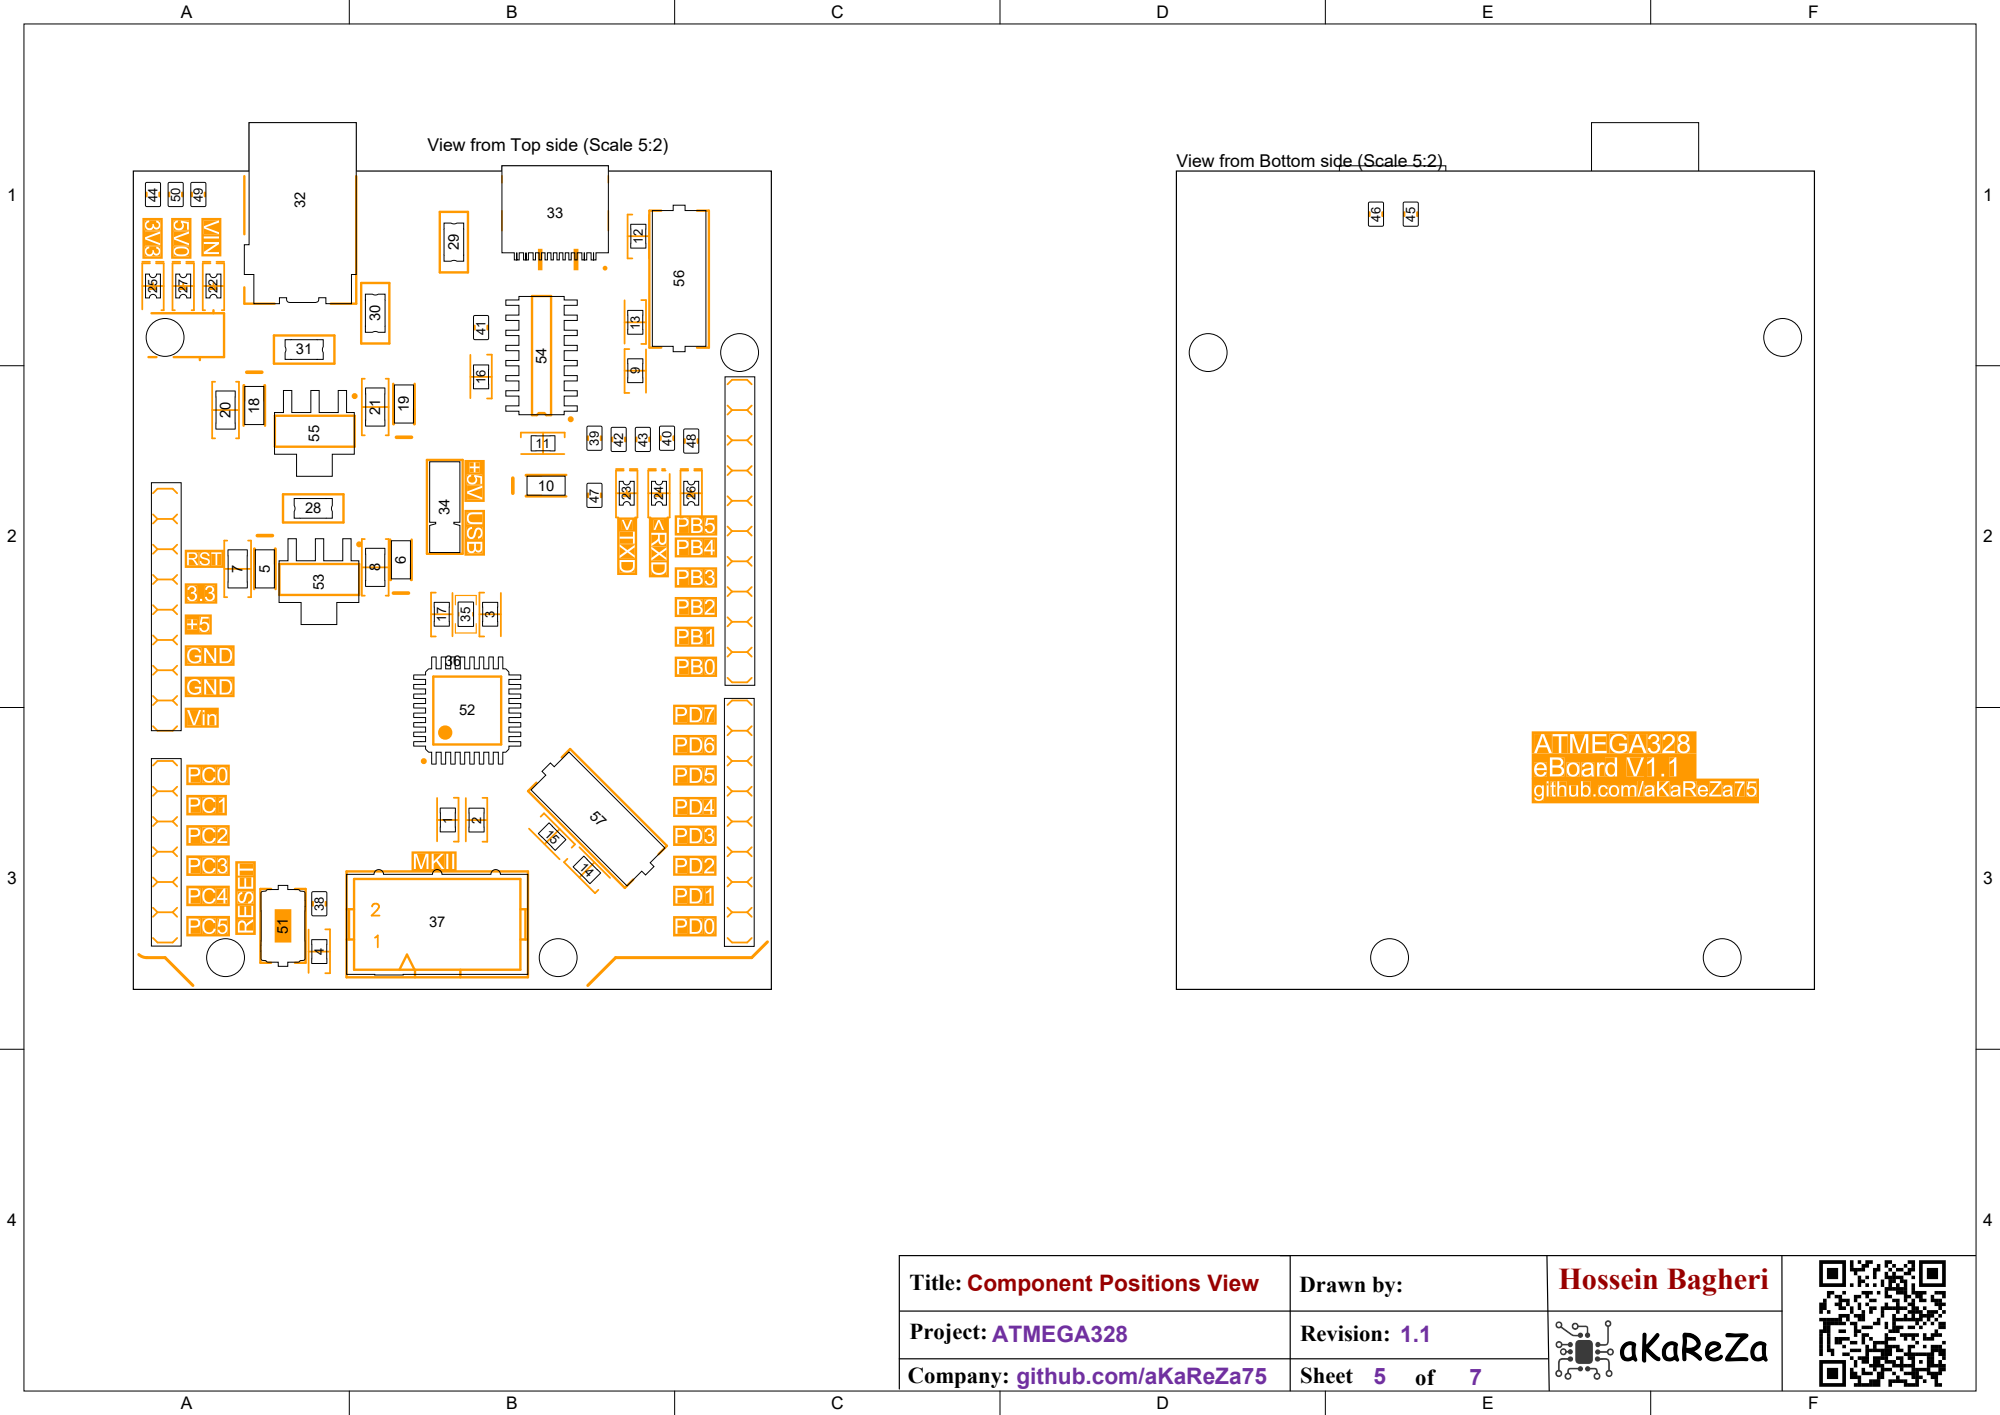
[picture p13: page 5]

View from Top side (Scale 5:2)

View from Bottom side (Scale 5:2)

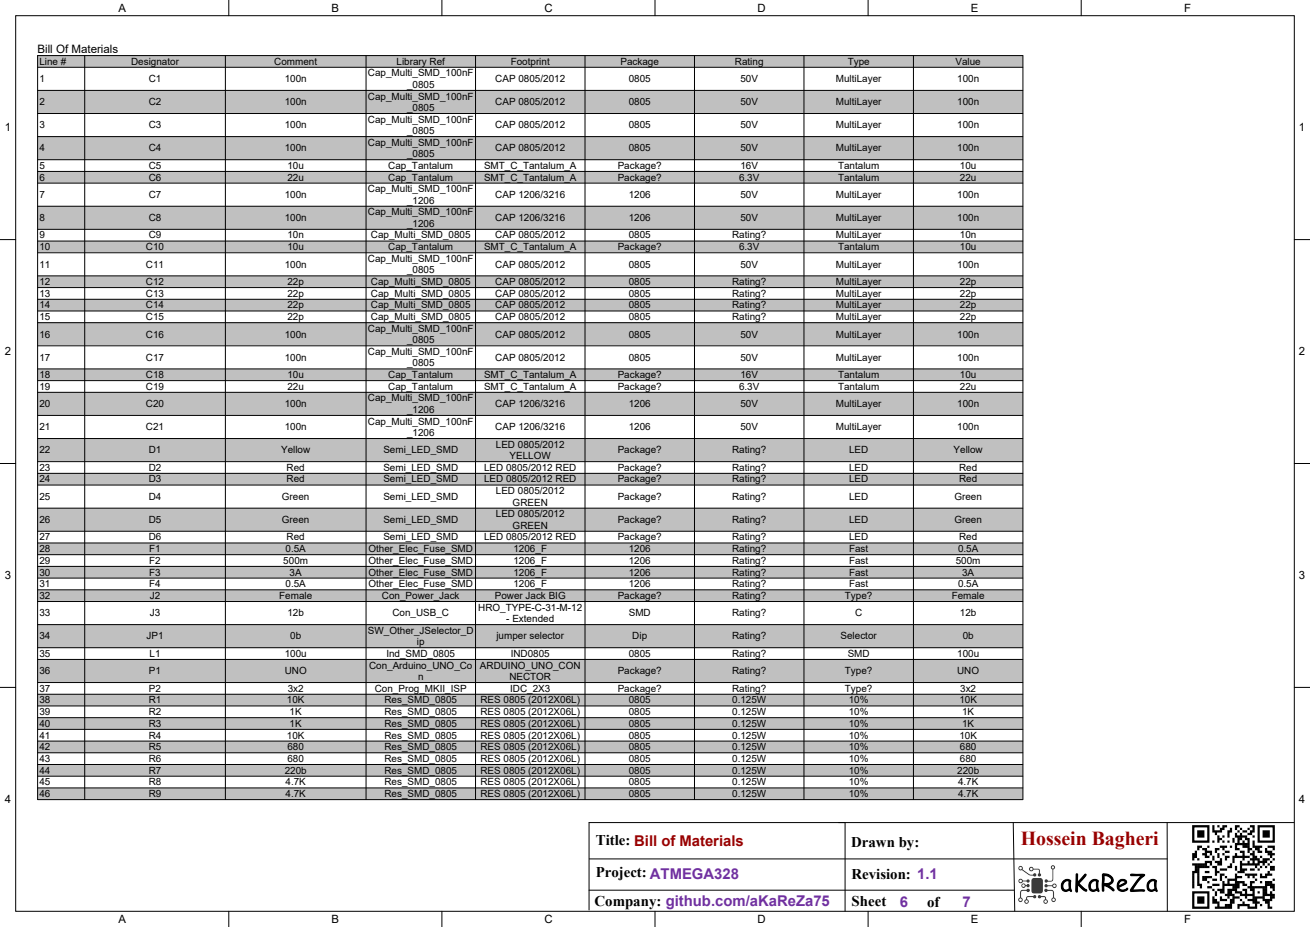
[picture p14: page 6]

Line # 123456789 | C3 | 100n | Cap_Multi_SMD_100nF _0805 | CAP 0805/2012 | 0805 | 50V | MultiLayer | 100n

Designator | Comment | Library Ref | Footprint | Package | Rating | Type | Value
C1 | 100n | Cap_Multi_SMD_100nF _0805 | CAP 0805/2012 | 0805 | 50V | MultiLayer | 100n

C2 | 100n | Cap_Multi_SMD_100nF _0805 | CAP 0805/2012 | 0805 | 50V | MultiLayer | 100n

C4 | 100n | Cap_Multi_SMD_100nF _0805 | CAP 0805/2012 | 0805 | 50V | MultiLayer | 100n

C5 | 10u | Cap_Tantalum | SMT_C_Tantalum_A | Package? | 16V | Tantalum | 10u
C6 | 22u | Cap_Tantalum | SMT_C_Tantalum_A | Package? | 6.3V | Tantalum | 22u
C7 | 100n | Cap_Multi_SMD_100nF _1206 | CAP 1206/3216 | 1206 | 50V | MultiLayer | 100n

C8 | 100n | Cap_Multi_SMD_100nF _1206 | CAP 1206/3216 | 1206 | 50V | MultiLayer | 100n

C9 | 10n | Cap_Multi_SMD_0805 | CAP 0805/2012 | 0805 | Rating? | MultiLayer | 10n

10 | C10 | 10u | Cap_Tantalum | SMT_C_Tantalum_A | Package? | 6.3V | Tantalum | 10u
11 | C11 | 100n | Cap_Multi_SMD_100nF _0805 | CAP 0805/2012 | 0805 | 50V | MultiLayer | 100n

12 | C12 | 22p | Cap_Multi_SMD_0805 | CAP 0805/2012 | 0805 | Rating? | MultiLayer | 22p
13 | C13 | 22p | Cap_Multi_SMD_0805 | CAP 0805/2012 | 0805 | Rating? | MultiLayer | 22p
14 | C14 | 22p | Cap_Multi_SMD_0805 | CAP 0805/2012 | 0805 | Rating? | MultiLayer | 22p
15 | C15 | 22p | Cap_Multi_SMD_0805 | CAP 0805/2012 | 0805 | Rating? | MultiLayer | 22p
16 | C16 | 100n | Cap_Multi_SMD_100nF _0805 | CAP 0805/2012 | 0805 | 50V | MultiLayer | 100n

17 | C17 | 100n | Cap_Multi_SMD_100nF _0805 | CAP 0805/2012 | 0805 | 50V | MultiLayer | 100n

18 | C18 | 10u | Cap_Tantalum | SMT_C_Tantalum_A | Package? | 16V | Tantalum | 10u
19 | C19 | 22u | Cap_Tantalum | SMT_C_Tantalum_A | Package? | 6.3V | Tantalum | 22u
20 | C20 | 100n | Cap_Multi_SMD_100nF _1206 | CAP 1206/3216 | 1206 | 50V | MultiLayer | 100n

21 | C21 | 100n | Cap_Multi_SMD_100nF _1206 | CAP 1206/3216 | 1206 | 50V | MultiLayer | 100n

22 | D1 | Yellow | Semi_LED_SMD | LED 0805/2012 YELLOW | Package? | Rating? | LED | Yellow

23 | D2 | Red | Semi_LED_SMD | LED 0805/2012 RED | Package? | Rating? | LED | Red
24 | D3 | Red | Semi_LED_SMD | LED 0805/2012 RED | Package? | Rating? | LED | Red
25 | D4 | Green | Semi_LED_SMD | LED 0805/2012 GREEN | Package? | Rating? | LED | Green

26 | D5 | Green | Semi_LED_SMD | LED 0805/2012 GREEN | Package? | Rating? | LED | Green

27 | D6 | Red | Semi_LED_SMD | LED 0805/2012 RED | Package? | Rating? | LED | Red
28 | F1 | 0.5A | Other_Elec_Fuse_SMD | 1206_F | 1206 | Rating? | Fast | 0.5A
29 | F2 | 500m | Other_Elec_Fuse_SMD | 1206_F | 1206 | Rating? | Fast | 500m
30 | F3 | 3A | Other_Elec_Fuse_SMD | 1206_F | 1206 | Rating? | Fast | 3A
31 | F4 | 0.5A | Other_Elec_Fuse_SMD | 1206_F | 1206 | Rating? | Fast | 0.5A
32 | J2 | Female | Con_Power_Jack | Power Jack BIG | Package? | Rating? | Type? C | Female
33 | J3 | 12b | Con_USB_C | HRO_TYPE-C-31-M-12 - Extended | SMD | Rating? | | 12b

34 | JP1 | 0b | SW_Other_JSelector_D ip | jumper selector | Dip | Rating? | Selector | 0b

35 | L1 | 100u | Ind_SMD_0805 | IND0805 | 0805 | Rating? | SMD | 100u
36 | P1 | UNO | Con_Arduino_UNO_Co n | ARDUINO_UNO_CON NECTOR | Package? | Rating? | Type? | UNO
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

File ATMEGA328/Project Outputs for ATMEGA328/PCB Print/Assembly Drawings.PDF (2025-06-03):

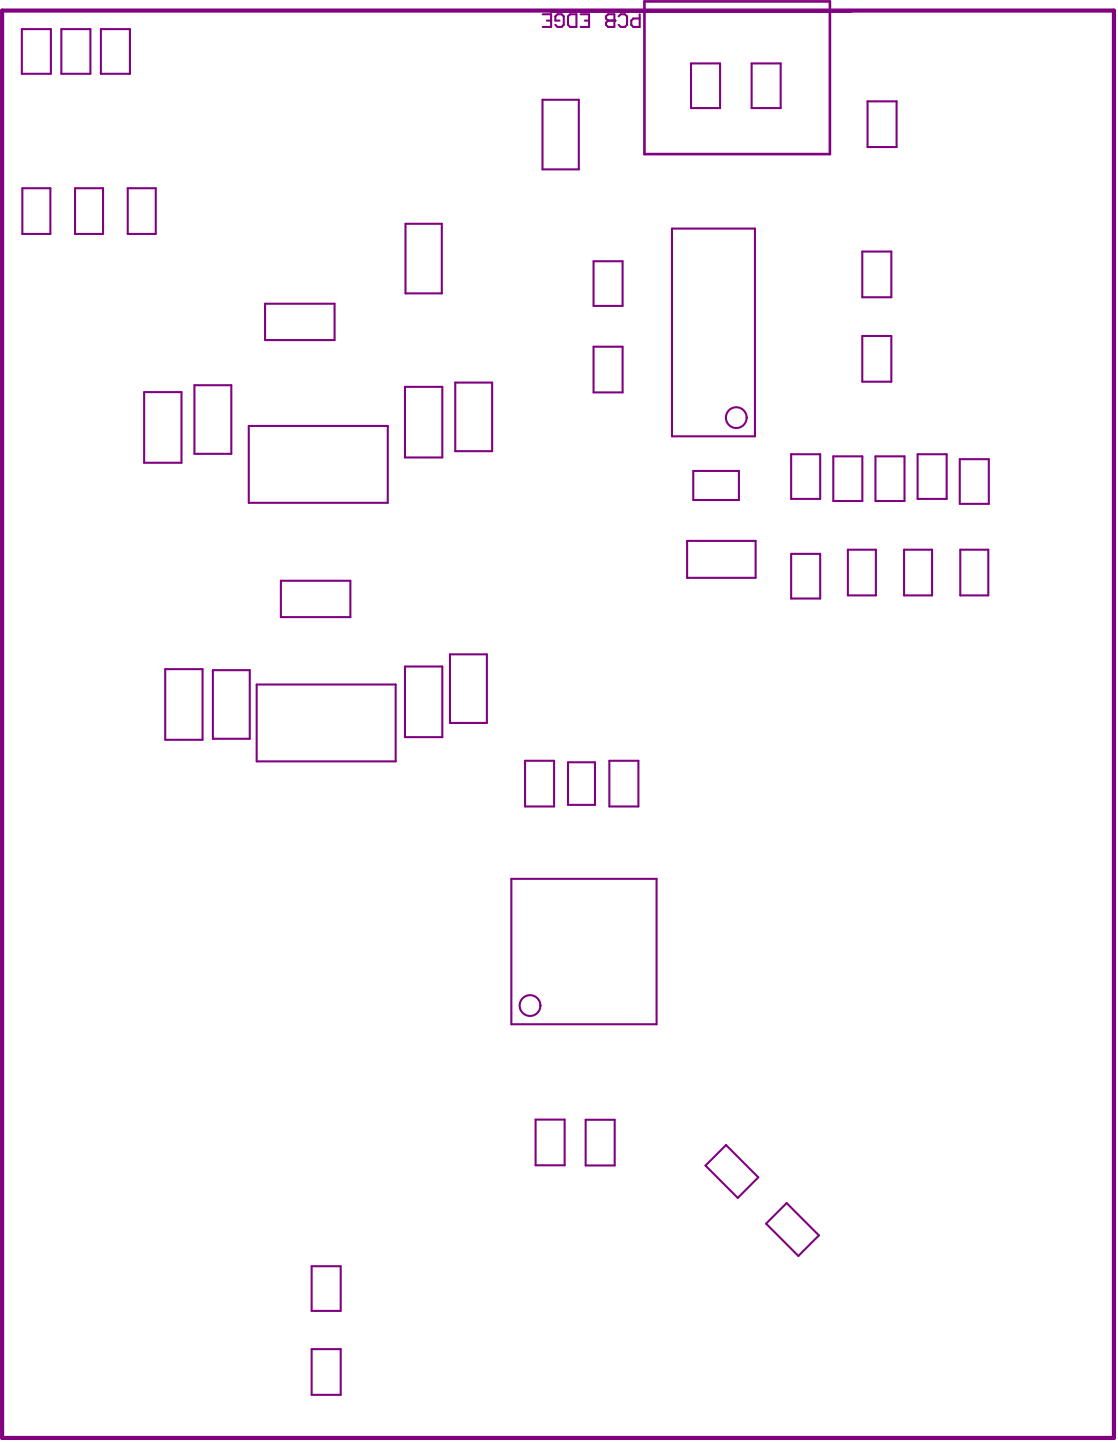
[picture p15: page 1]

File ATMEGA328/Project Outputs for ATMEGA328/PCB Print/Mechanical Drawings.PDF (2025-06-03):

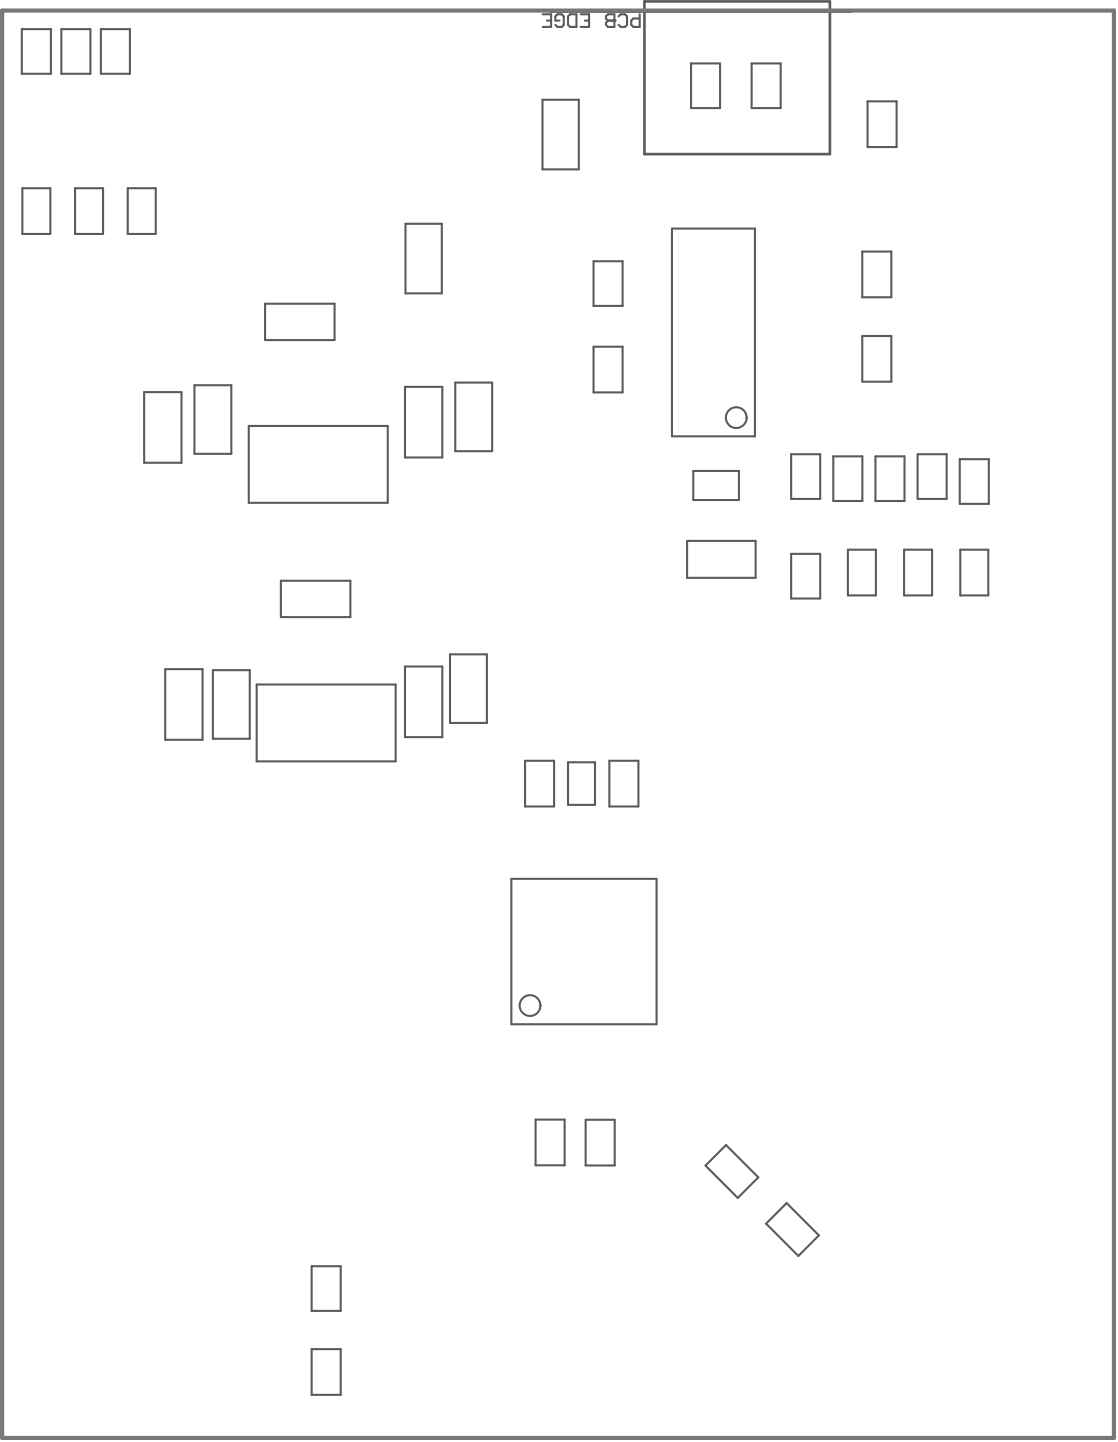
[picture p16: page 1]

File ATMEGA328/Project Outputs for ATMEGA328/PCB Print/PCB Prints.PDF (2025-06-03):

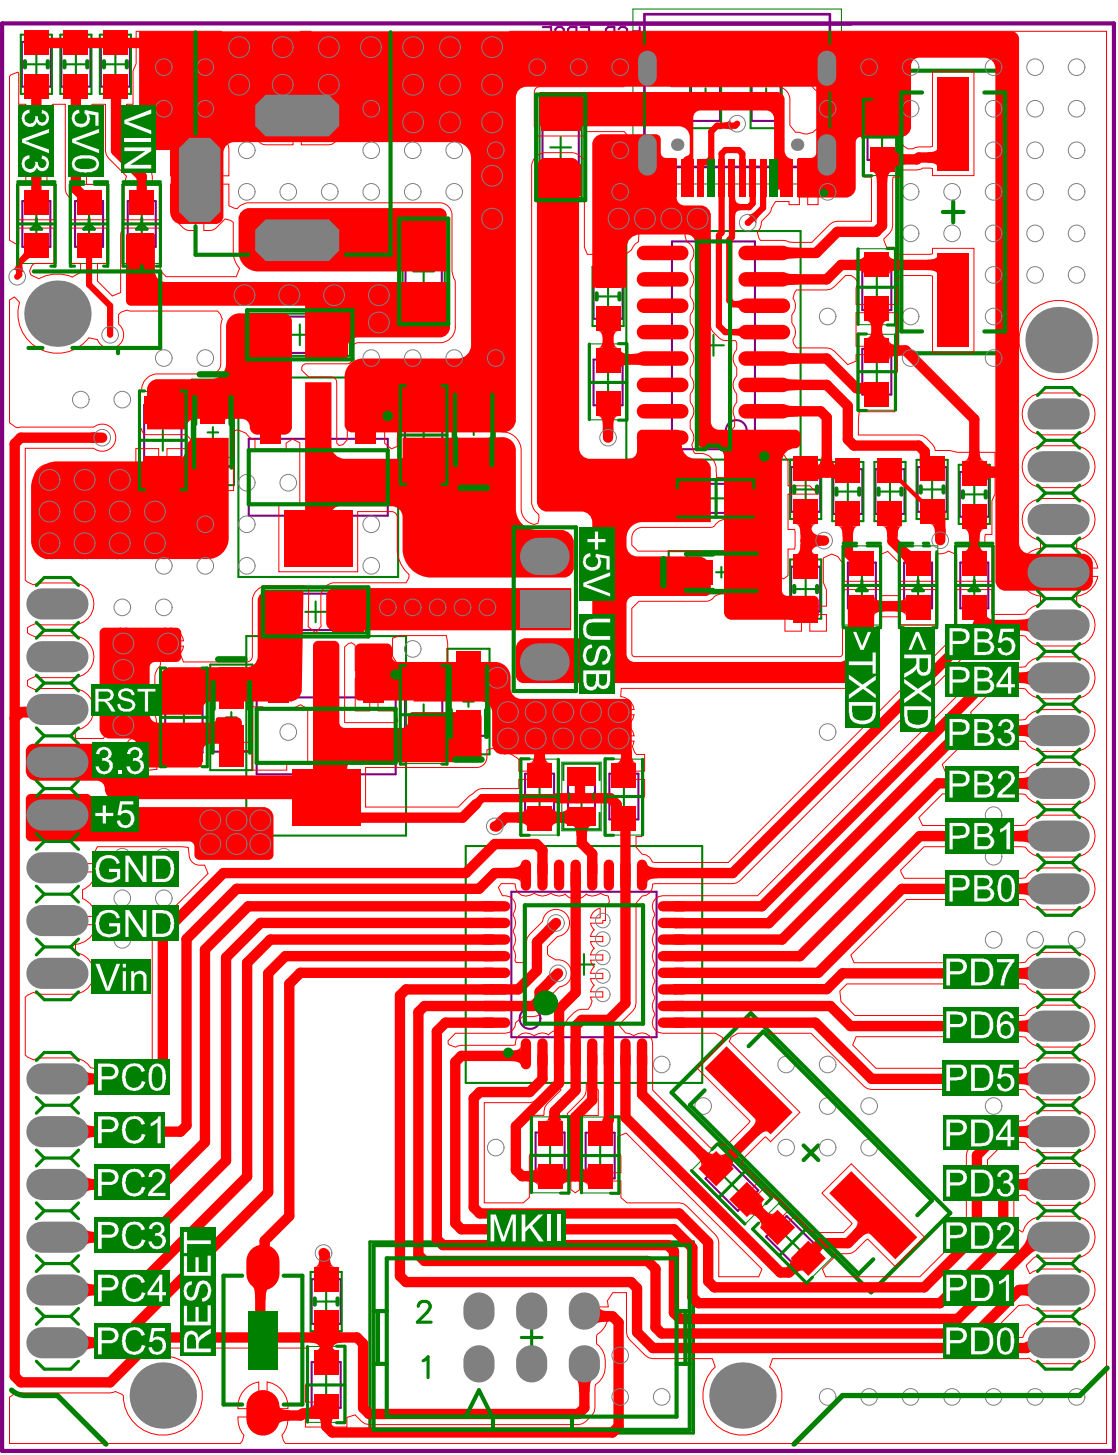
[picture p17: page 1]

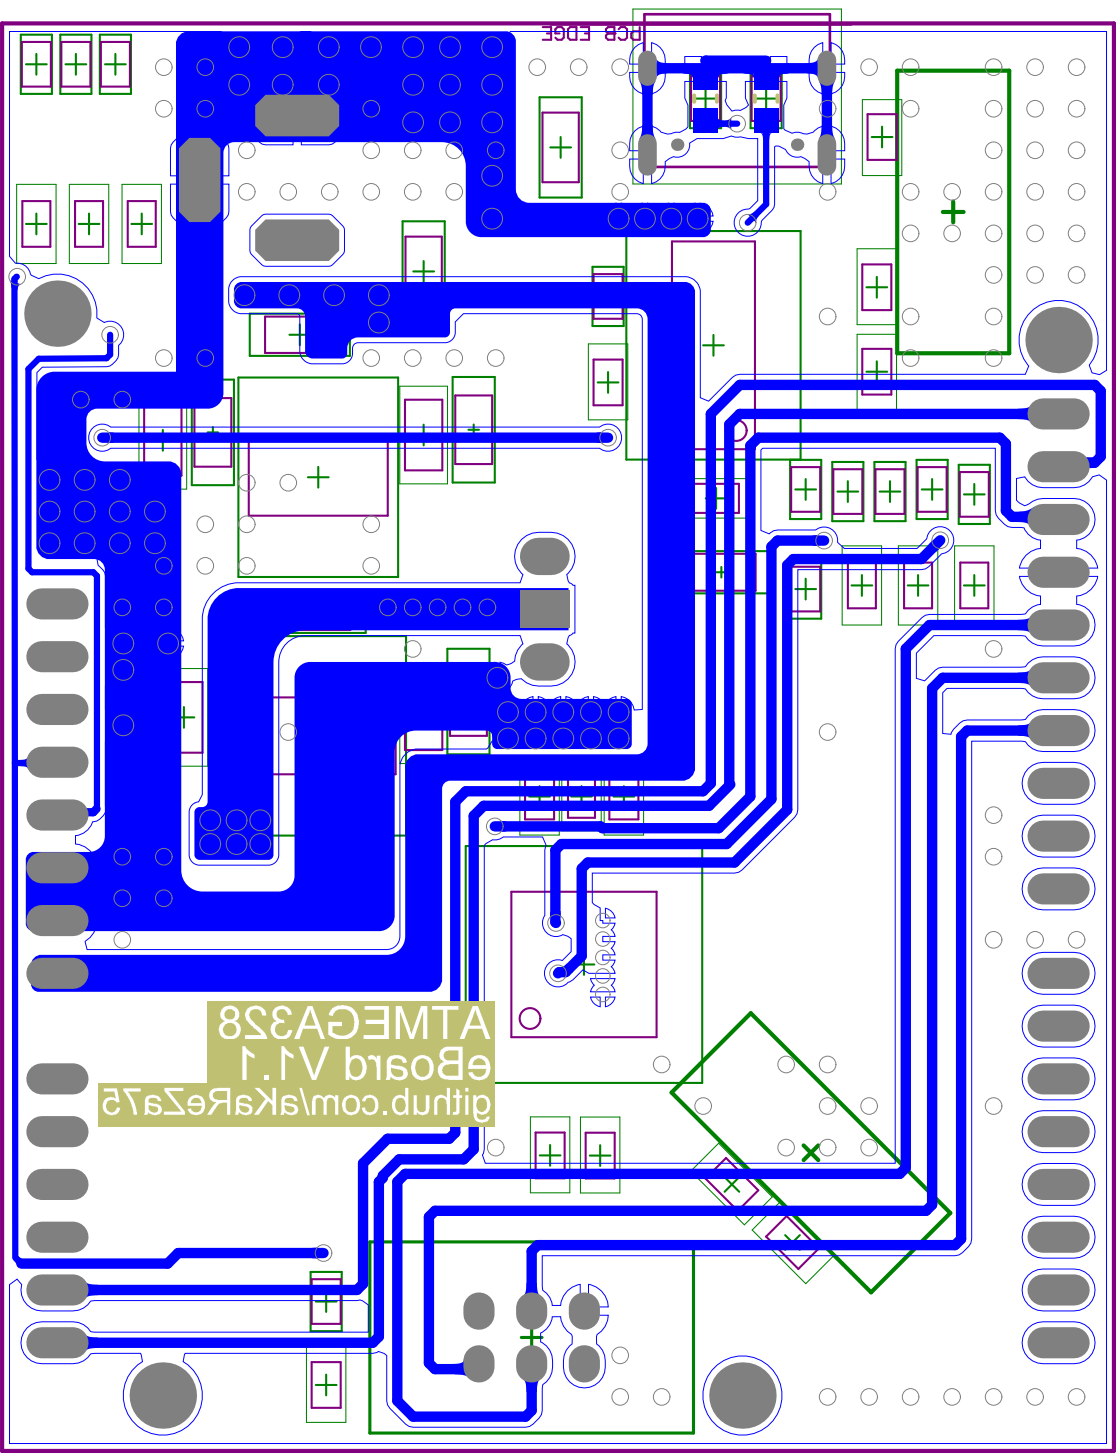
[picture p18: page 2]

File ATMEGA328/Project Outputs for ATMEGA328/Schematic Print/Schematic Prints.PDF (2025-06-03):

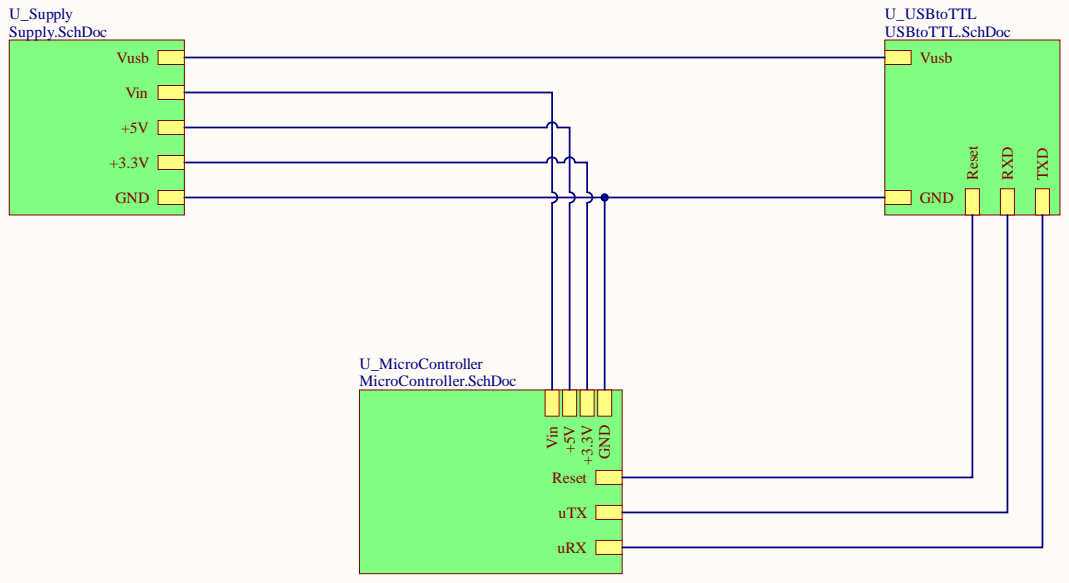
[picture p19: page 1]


1 | 8 | 1 4 PB2




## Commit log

2024-12-30 change CH340G Supply
    [Sheet1.SchDoc]
2024-12-30 add new scheets
    [ATMEGA328.PrjPcb, Main.SchDoc, Sheet1.SchDoc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]
2024-12-30 change design to Hierachical
    [ATMEGA328.PrjPcb, Main.SchDoc, MicroController.SchDoc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]
2024-12-30 Routing is done
    [ATMEGA328.PrjPcb, USBtoTTL.SchDoc]
2025-01-01 add final change such as logo and designators
    [USBtoTTL.SchDoc]
2025-02-08 Update Repo
    [Arduino_7Segments.PrjPcb, PCB1.PcbDoc, Sheet1.SchDoc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]
2025-02-21 Update all components with aKaReZa lib
    [ATMEGA328.PrjPcb, MicroController.SchDoc, Supply.SchDoc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]
2025-02-21 Update PCB
2025-03-08 prepare for fabrication and add documents
    [ATMEGA328.PrjPcb, MicroController.SchDoc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]
2025-03-10 Update Documents
    [PCB.PcbDoc]
2025-03-10 UPdate files
    [PCB.PcbDoc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]
2025-06-03 Solve issues
    [ATMEGA328.PrjPcb, Supply.SchDoc, USBtoTTL.SchDoc]
2025-06-03 Revole issues
    [ATMEGA328.PrjPcb, Main.SchDoc, MicroController.SchDoc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]
